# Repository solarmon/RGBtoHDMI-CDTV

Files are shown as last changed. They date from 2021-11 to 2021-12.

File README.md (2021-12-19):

# RGBtoHDMI-CDTV

## Introduction

This is an RGBtoHDMI solution is based on the original work by **hoglet67** and **IanSB**:

hoglet67:
https://github.com/hoglet67/RGBtoHDMI

IanSB:
https://github.com/IanSB/RGBtoHDMI

The solution is based on the RGBtoHDMI CPLD based hardware design by **LinuxJedi**:

https://github.com/LinuxJedi/AmigaRGBtoHDMI

Special mention to **c0pperdragon** for the original RGBtoHDMI board solution for the Amiga:

https://github.com/c0pperdragon/Amiga-Digital-Video

## Wiki

Please see the [wiki](https://github.com/solarmon/RGBtoHDMI-CDTV/wiki) for further details:

* [RGBtoHDMI CDTV Quick Start Guide](https://github.com/solarmon/RGBtoHDMI-CDTV/wiki/RGBtoHDMI-CDTV-Quick-Start-Guide)
* [RGBtoHDMI CDTV BoM](https://github.com/solarmon/RGBtoHDMI-CDTV/wiki/RGBtoHDMI-CDTV-BoM)
* [RGBtoHDMI CDTV Build Guide](https://github.com/solarmon/RGBtoHDMI-CDTV/wiki/RGBtoHDMI-CDTV-Build-Guide)

## Support

Please raise a [support ticket](https://github.com/solarmon/RGBtoHDMI-CDTV/issues) for any issues with this project content and design files.

## Solution

This RGBtoHDMI solution has been designed to fit in to the **Video Slot** of a **Commodore CDTV**. It replaces the existing RF and composite video card, as well as providing a **bypass** for the video signals to go to the **RGB** video port.

A breakout board is used to send the digital RGB signals from the Denise video chip, over a 18-pin FFC flex cable, to the main RGBtoHDMI board sitting in the Video Slot.

The mini HDMI connector of the **Raspberry Pi Zero** is presented directly on the face plate, along with three push buttons to control the RGBtoHDMI **OSD** menu.

This LinuxJedi CPLD based version supports either **OCS** or **ECS** Denise. There is no jumper required - you just need to make sure you **auto-calibrate** it using the OSD menu.

As with all the other RGBtoHDMI solution, **audio over HDMI** is currently **NOT supported**. This board does have breakout points for the **AUDL** and **AUDR** but is not used.

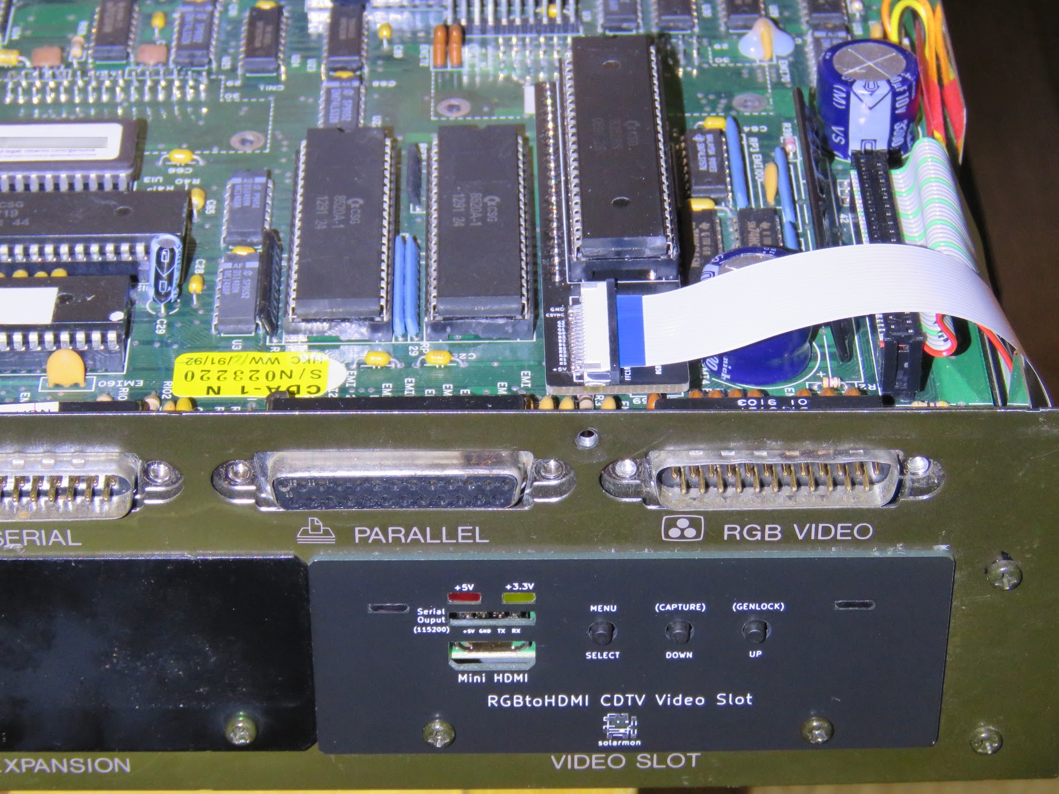
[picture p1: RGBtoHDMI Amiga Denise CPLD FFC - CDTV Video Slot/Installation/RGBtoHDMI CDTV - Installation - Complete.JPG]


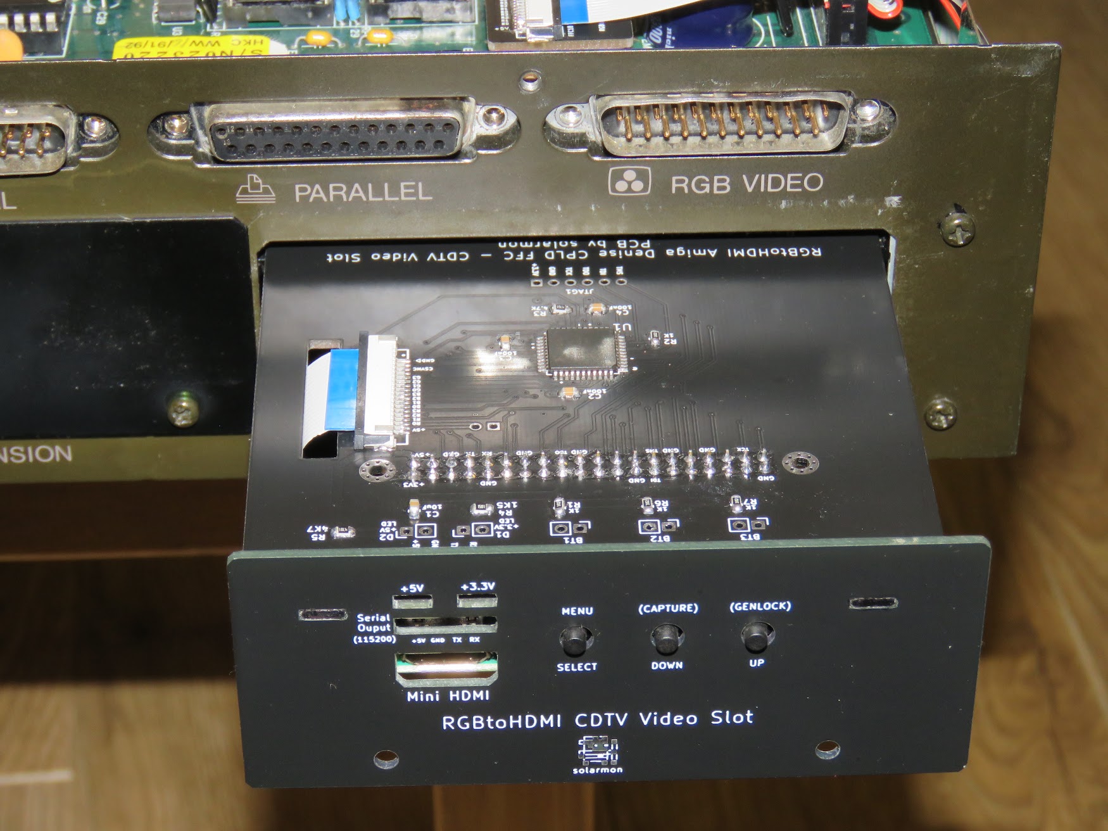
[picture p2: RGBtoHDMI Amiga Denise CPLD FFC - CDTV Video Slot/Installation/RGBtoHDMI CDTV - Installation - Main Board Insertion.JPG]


(...yes, I know the serial port and LEDs are missing in this picture! Oops!)

## Design

### RGBtoHDMI CDTV Main Board

Design files: https://github.com/solarmon/RGBtoHDMI-CDTV/tree/main/RGBtoHDMI%20Amiga%20Denise%20CPLD%20FFC%20-%20CDTV%20Video%20Slot

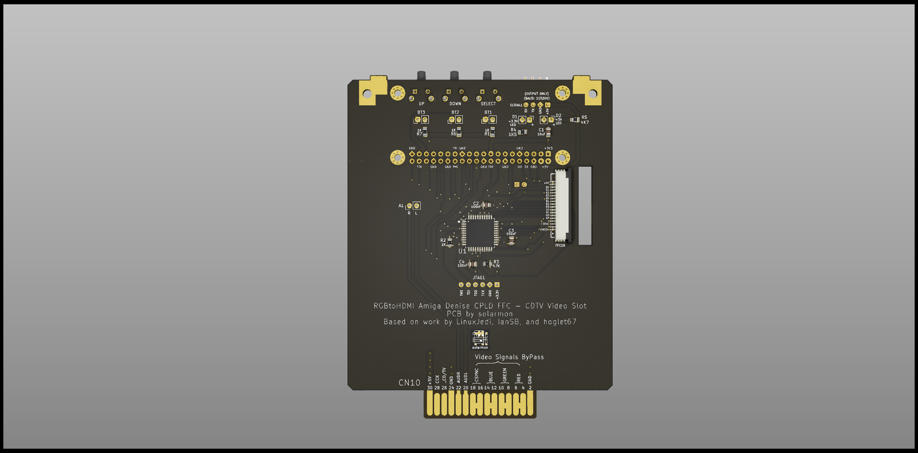
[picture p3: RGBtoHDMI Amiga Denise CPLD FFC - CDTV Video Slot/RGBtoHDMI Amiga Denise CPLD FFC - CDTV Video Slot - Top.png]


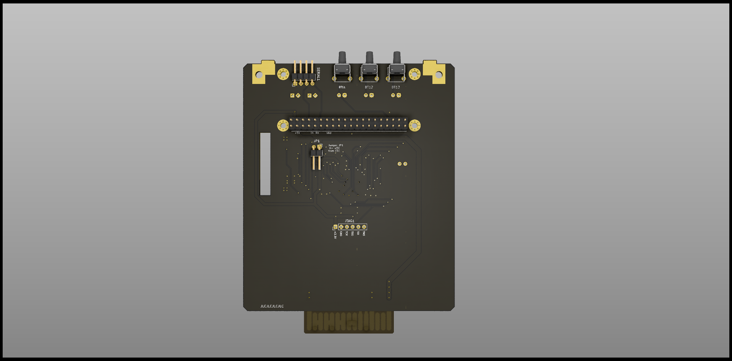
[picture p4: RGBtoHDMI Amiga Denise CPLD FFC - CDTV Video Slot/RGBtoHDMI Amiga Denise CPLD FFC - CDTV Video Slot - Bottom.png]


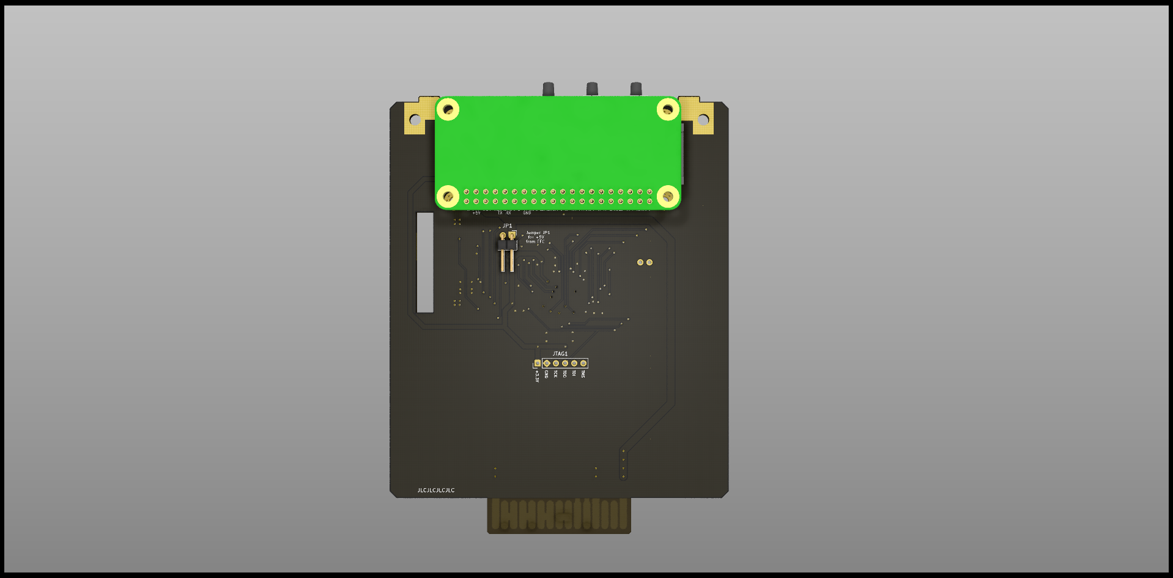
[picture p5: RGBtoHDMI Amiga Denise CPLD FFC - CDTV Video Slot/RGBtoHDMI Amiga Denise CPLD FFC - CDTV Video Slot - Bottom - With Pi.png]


### RGBtoHDMI CDTV Face Plate

Design files: https://github.com/solarmon/RGBtoHDMI-CDTV/tree/main/RGBtoHDMI%20Amiga%20Denise%20CPLD%20FFC%20-%20CDTV%20Video%20Slot

The face plate for the RGBtoHDMI CDTV board is also a PCB. It is attached to the main board using guide slots that has solder pads so that it can be soldered together.

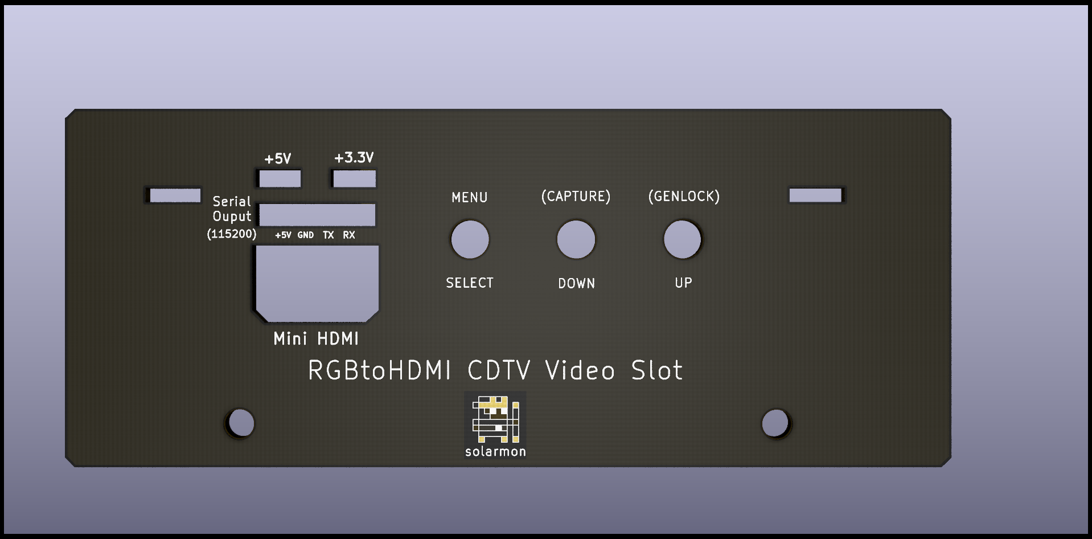
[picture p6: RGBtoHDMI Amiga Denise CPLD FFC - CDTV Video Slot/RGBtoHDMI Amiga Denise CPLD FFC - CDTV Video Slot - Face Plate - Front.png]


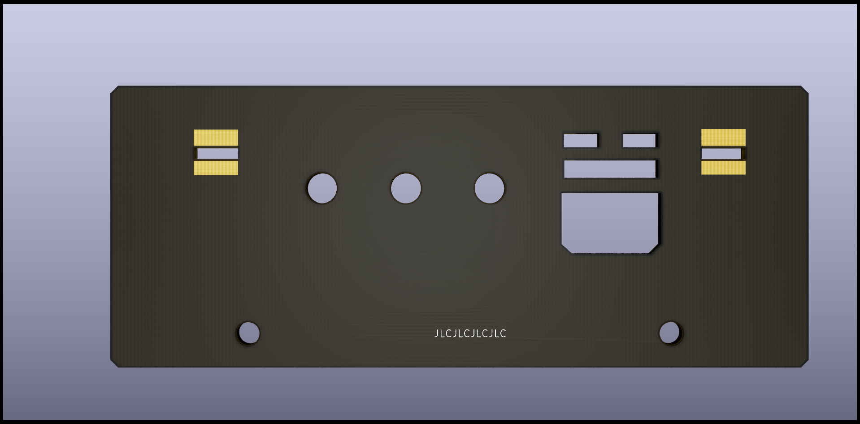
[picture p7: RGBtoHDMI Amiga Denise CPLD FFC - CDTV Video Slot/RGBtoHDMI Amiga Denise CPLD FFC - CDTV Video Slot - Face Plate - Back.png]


### RGBtoHDMI CDTV Denise Breakout board v1

Design files: https://github.com/solarmon/RGBtoHDMI-CDTV/tree/main/RGBtoHDMI%20Amiga%20Denise%20DIP%20Breakout%20FFC%20-%20CDTV

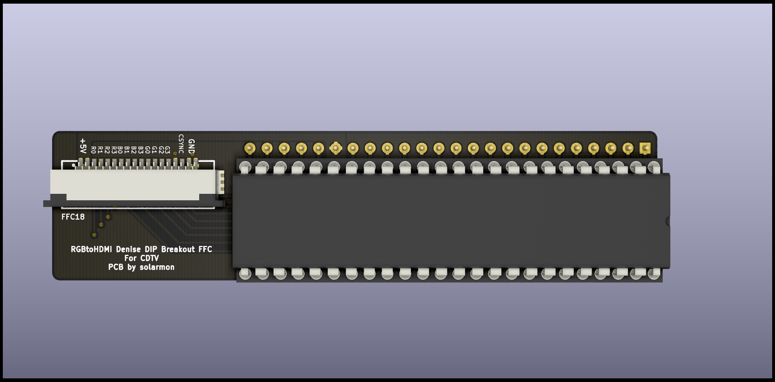
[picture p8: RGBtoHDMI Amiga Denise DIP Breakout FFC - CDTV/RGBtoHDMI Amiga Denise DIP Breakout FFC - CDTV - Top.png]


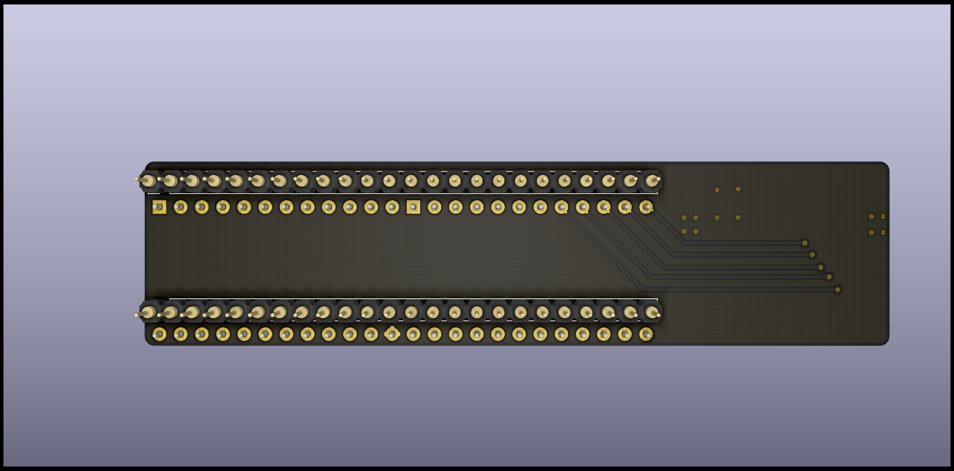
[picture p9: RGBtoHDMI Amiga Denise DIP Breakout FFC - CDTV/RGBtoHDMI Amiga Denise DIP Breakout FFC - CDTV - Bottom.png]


### RGBtoHDMI CDTV Denise Breakout board v2

Design files: https://github.com/solarmon/RGBtoHDMI-CDTV/tree/main/RGBtoHDMI%20Amiga%20Denise%20DIP%20Breakout%20FFC%20-%20CDTV%20v2

The v2 breakout board has a lower profile by using female round pins that act both as the socket for the Denise chip, as well as the pin to go in to the Denise socket on the CDTV.

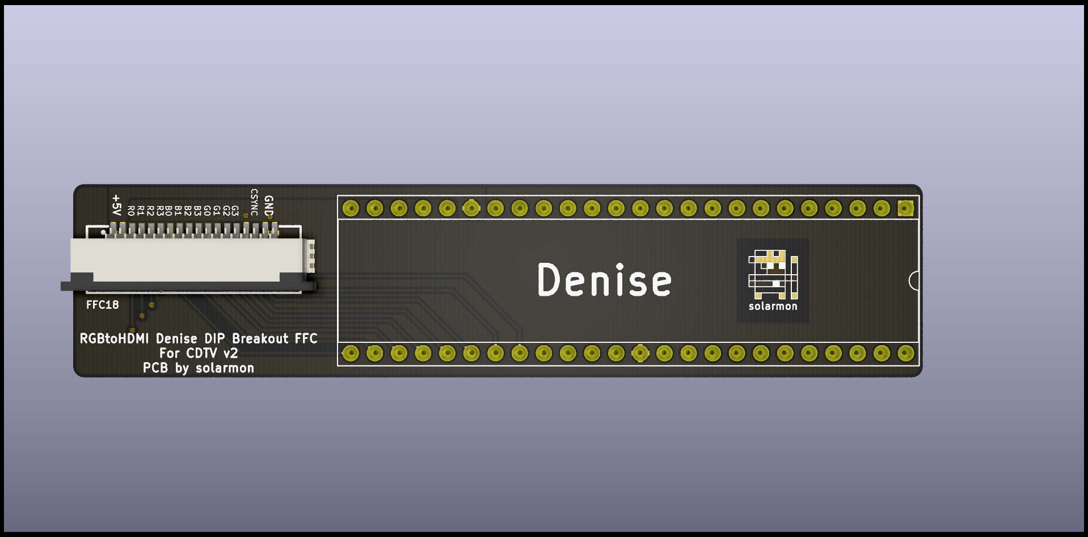
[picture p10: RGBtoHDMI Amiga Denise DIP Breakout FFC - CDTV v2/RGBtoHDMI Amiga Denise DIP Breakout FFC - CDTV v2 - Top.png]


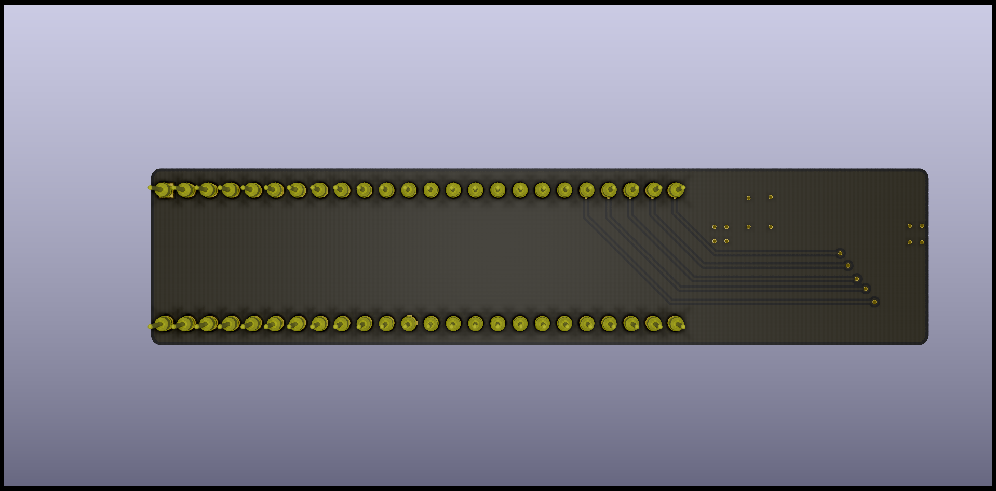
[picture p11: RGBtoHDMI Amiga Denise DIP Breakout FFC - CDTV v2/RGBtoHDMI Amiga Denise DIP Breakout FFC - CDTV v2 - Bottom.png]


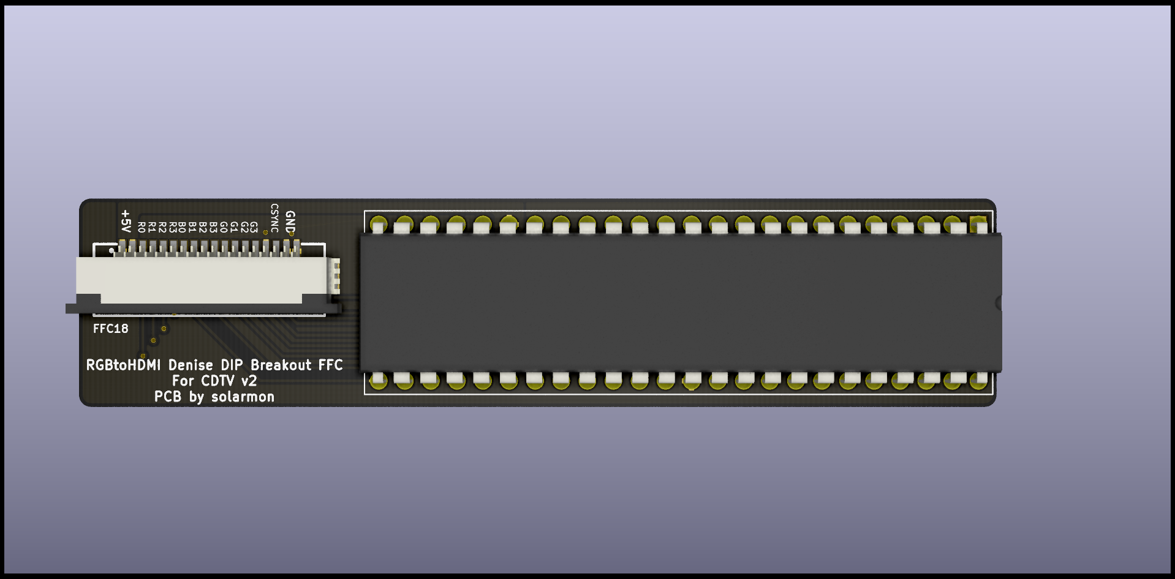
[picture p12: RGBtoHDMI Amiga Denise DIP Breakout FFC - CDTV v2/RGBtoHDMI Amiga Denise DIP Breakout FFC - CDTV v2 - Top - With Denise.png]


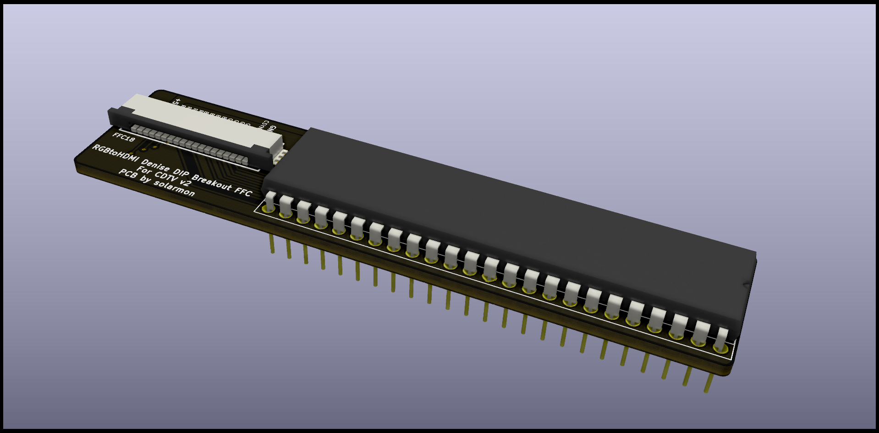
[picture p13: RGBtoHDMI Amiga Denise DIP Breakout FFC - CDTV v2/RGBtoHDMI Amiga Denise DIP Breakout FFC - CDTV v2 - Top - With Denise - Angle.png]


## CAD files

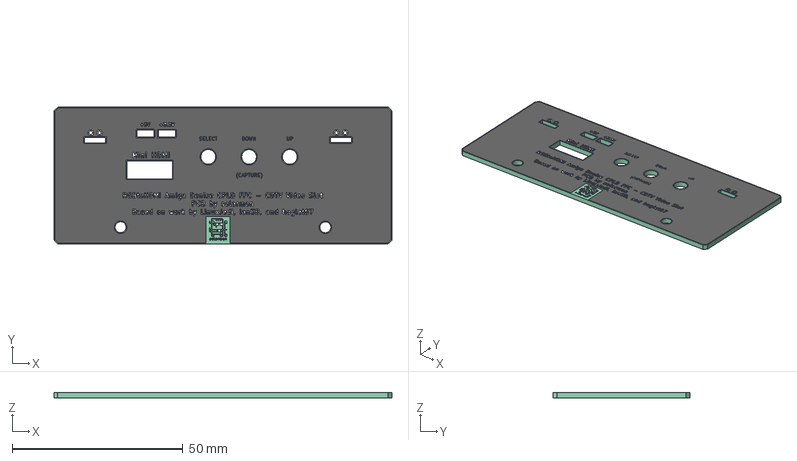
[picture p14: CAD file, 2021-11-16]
RGBtoHDMI Amiga Denise CPLD FFC - CDTV Video Slot/CDTV Front plate.FCStd
99.0 x 40.0 x 1.69 mm
Pcb_8674
topPads_8674
topZones_8674
botPads_8674
botZones_8674
topSilks_deb6

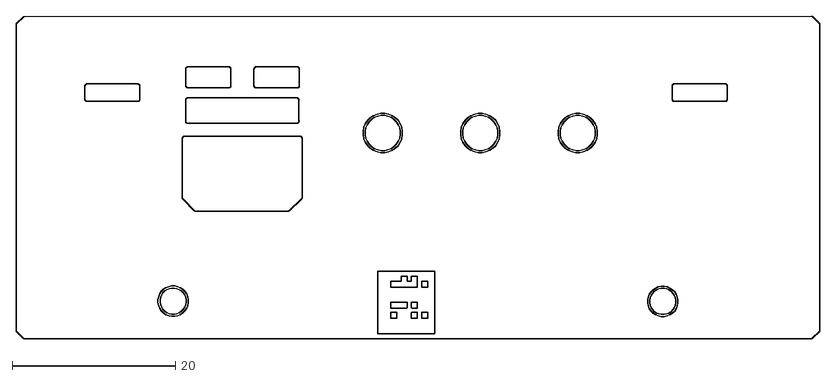
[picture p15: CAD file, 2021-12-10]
RGBtoHDMI Amiga Denise CPLD FFC - CDTV Video Slot/gerbers/face-plate/RGBtoHDMI Amiga Denise CPLD FFC - CDTV Video Slot - Face Plate-F_Cu.dxf
98.4 x 39.4

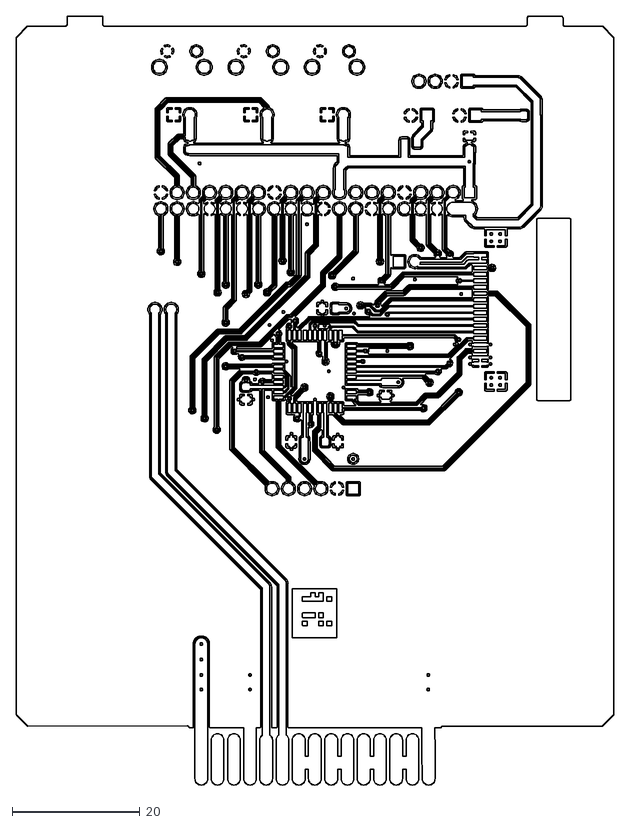
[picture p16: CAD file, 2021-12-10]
RGBtoHDMI Amiga Denise CPLD FFC - CDTV Video Slot/gerbers/video-slot/RGBtoHDMI Amiga Denise CPLD FFC - CDTV Video Slot-F_Cu.dxf
93.4 x 120.3

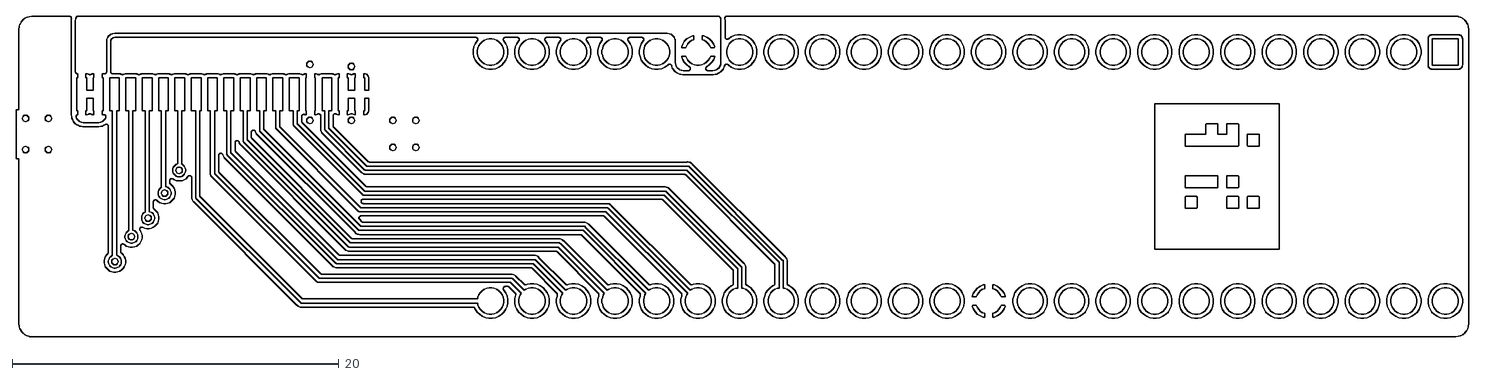
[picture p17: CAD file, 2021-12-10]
RGBtoHDMI Amiga Denise DIP Breakout FFC - CDTV v2/gerber/RGBtoHDMI Amiga Denise DIP Breakout FFC - CDTV v2-F_Cu.dxf
88.9 x 19.6

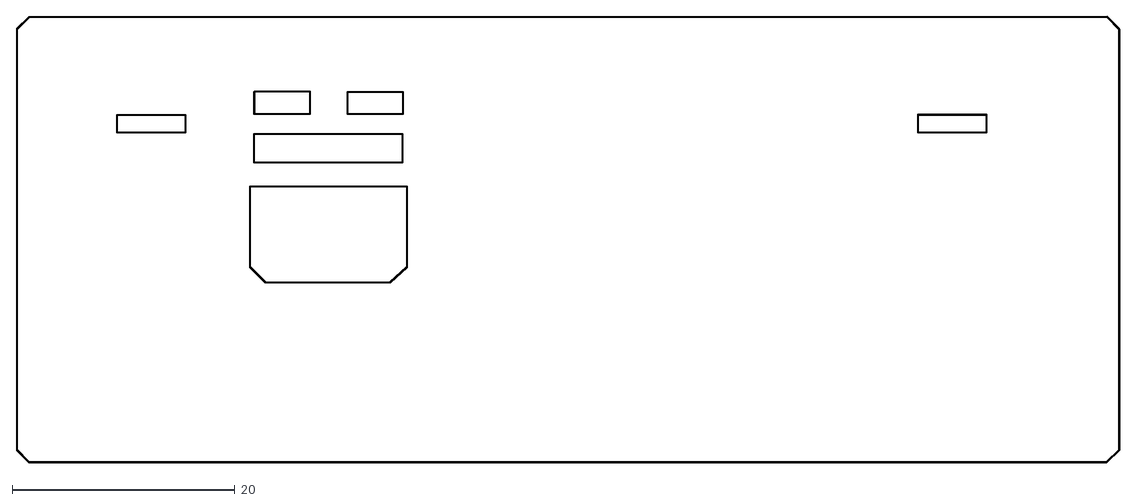
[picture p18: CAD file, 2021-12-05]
RGBtoHDMI Amiga Denise CPLD FFC - CDTV Video Slot/gerbers/face-plate/RGBtoHDMI Amiga Denise CPLD FFC - CDTV Video Slot - Face Plate-Edge_Cuts.dxf
99.0 x 40.1

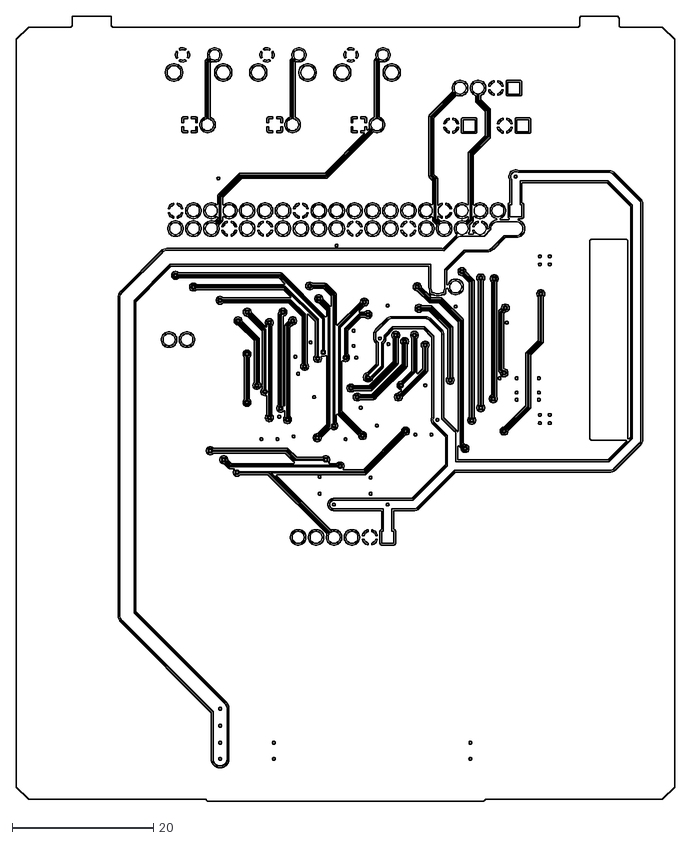
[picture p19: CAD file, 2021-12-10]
RGBtoHDMI Amiga Denise CPLD FFC - CDTV Video Slot/gerbers/video-slot/RGBtoHDMI Amiga Denise CPLD FFC - CDTV Video Slot-B_Cu.dxf
93.4 x 111.3

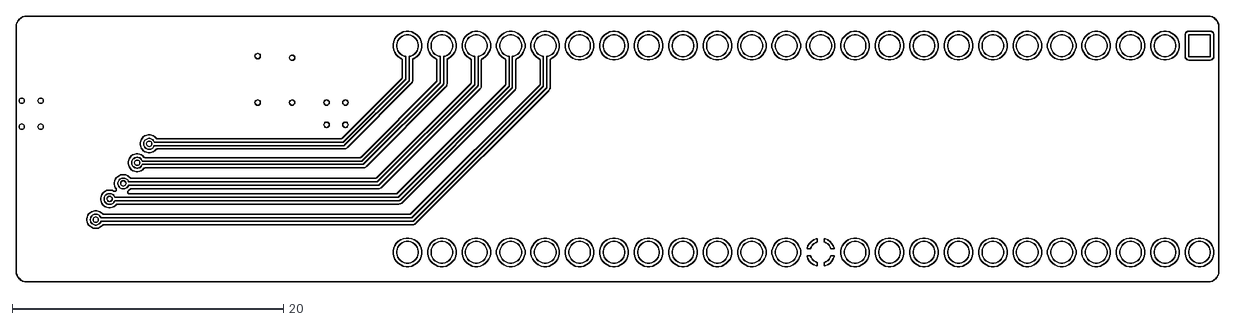
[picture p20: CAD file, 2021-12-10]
RGBtoHDMI Amiga Denise DIP Breakout FFC - CDTV v2/gerber/RGBtoHDMI Amiga Denise DIP Breakout FFC - CDTV v2-B_Cu.dxf
88.7 x 19.6

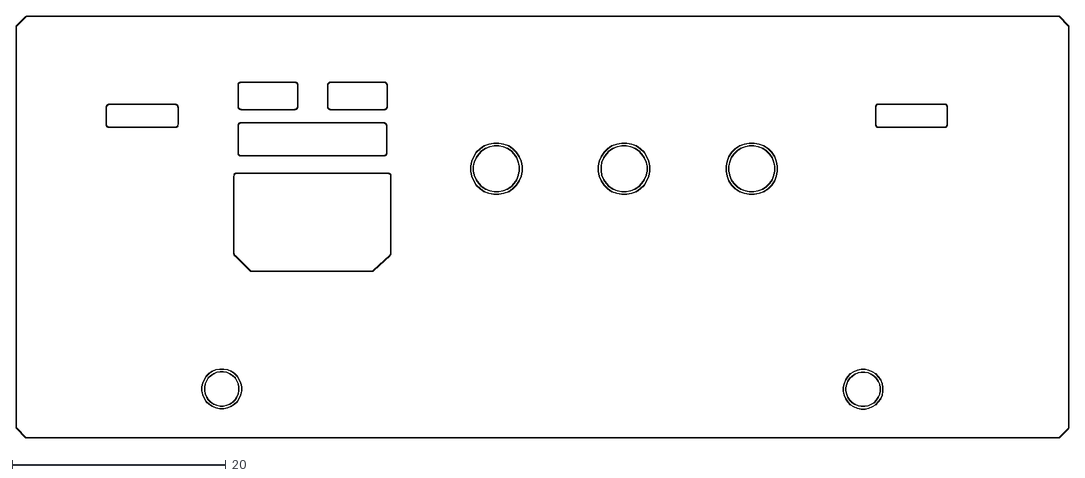
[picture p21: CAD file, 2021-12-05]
RGBtoHDMI Amiga Denise CPLD FFC - CDTV Video Slot/gerbers/face-plate/RGBtoHDMI Amiga Denise CPLD FFC - CDTV Video Slot - Face Plate-B_Cu.dxf
98.4 x 39.4

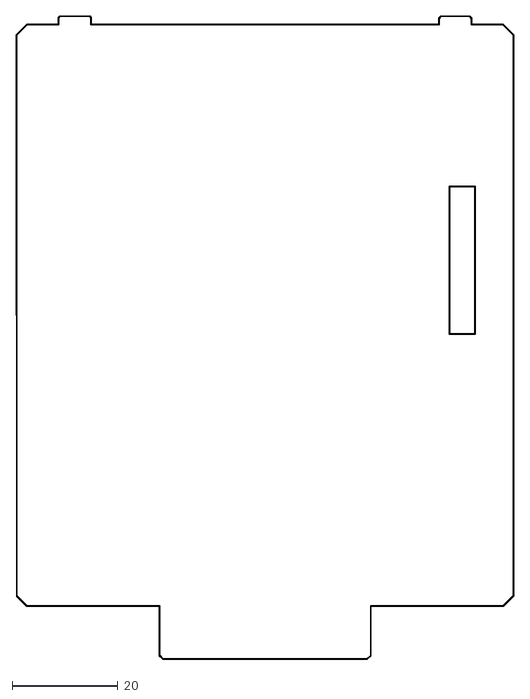
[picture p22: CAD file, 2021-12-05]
RGBtoHDMI Amiga Denise CPLD FFC - CDTV Video Slot/gerbers/video-slot/RGBtoHDMI Amiga Denise CPLD FFC - CDTV Video Slot-Edge_Cuts.dxf
94.0 x 121.6

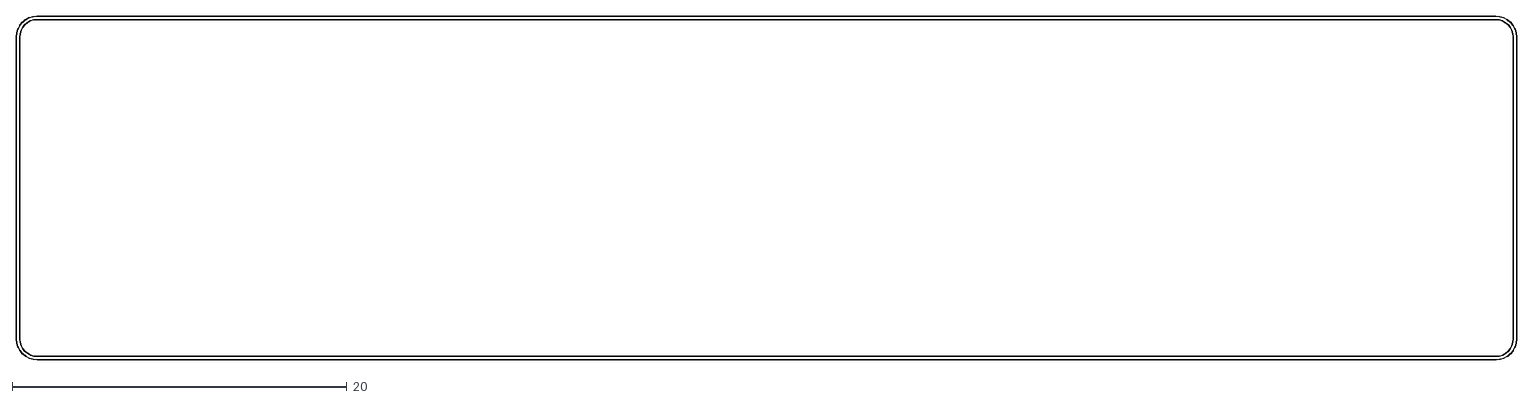
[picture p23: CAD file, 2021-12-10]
RGBtoHDMI Amiga Denise DIP Breakout FFC - CDTV v2/gerber/RGBtoHDMI Amiga Denise DIP Breakout FFC - CDTV v2-Edge_Cuts.dxf
89.6 x 20.5

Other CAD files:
RGBtoHDMI Amiga Denise CPLD FFC - CDTV Video Slot/gerbers/face-plate/RGBtoHDMI Amiga Denise CPLD FFC - CDTV Video Slot - Face Plate-B_Mask.dxf
RGBtoHDMI Amiga Denise CPLD FFC - CDTV Video Slot/gerbers/face-plate/RGBtoHDMI Amiga Denise CPLD FFC - CDTV Video Slot - Face Plate-B_SilkS.dxf
RGBtoHDMI Amiga Denise CPLD FFC - CDTV Video Slot/gerbers/face-plate/RGBtoHDMI Amiga Denise CPLD FFC - CDTV Video Slot - Face Plate-F_Mask.dxf
RGBtoHDMI Amiga Denise CPLD FFC - CDTV Video Slot/gerbers/face-plate/RGBtoHDMI Amiga Denise CPLD FFC - CDTV Video Slot - Face Plate-F_SilkS.dxf
RGBtoHDMI Amiga Denise CPLD FFC - CDTV Video Slot/gerbers/video-slot/RGBtoHDMI Amiga Denise CPLD FFC - CDTV Video Slot-B_Mask.dxf
RGBtoHDMI Amiga Denise CPLD FFC - CDTV Video Slot/gerbers/video-slot/RGBtoHDMI Amiga Denise CPLD FFC - CDTV Video Slot-B_SilkS.dxf
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

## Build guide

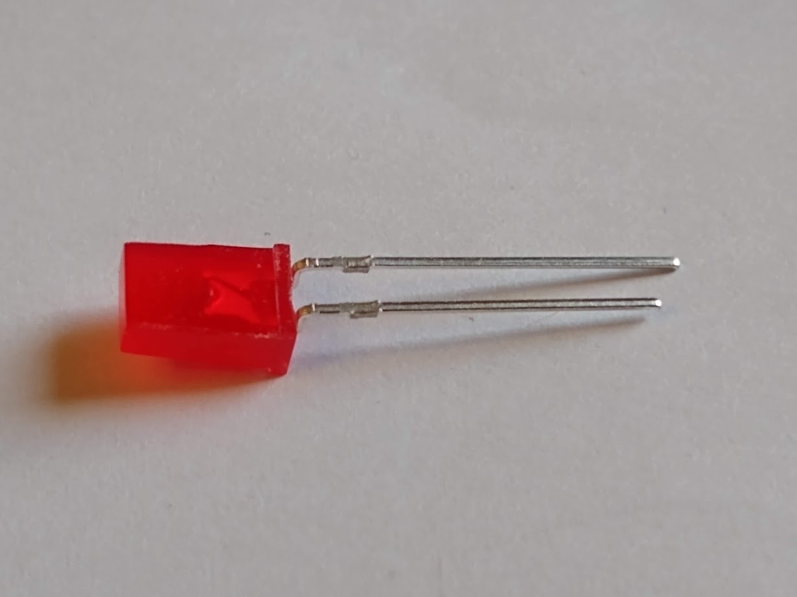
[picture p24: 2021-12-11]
RGBtoHDMI Amiga Denise CPLD FFC - CDTV Video Slot/Installation/RGBtoHDMI CDTV - LED - Legs Bent Back.jpg

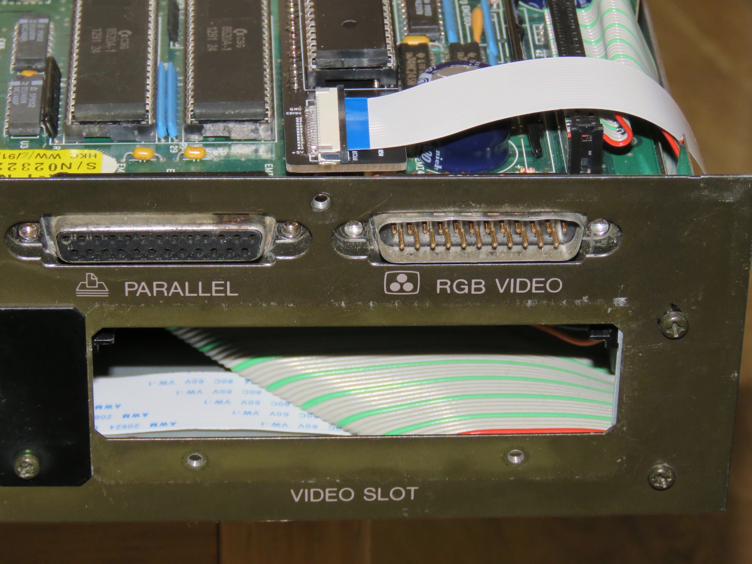
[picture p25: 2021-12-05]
RGBtoHDMI Amiga Denise CPLD FFC - CDTV Video Slot/Installation/RGBtoHDMI CDTV - Installation - Denise Break and Flex Cable - Rear.JPG

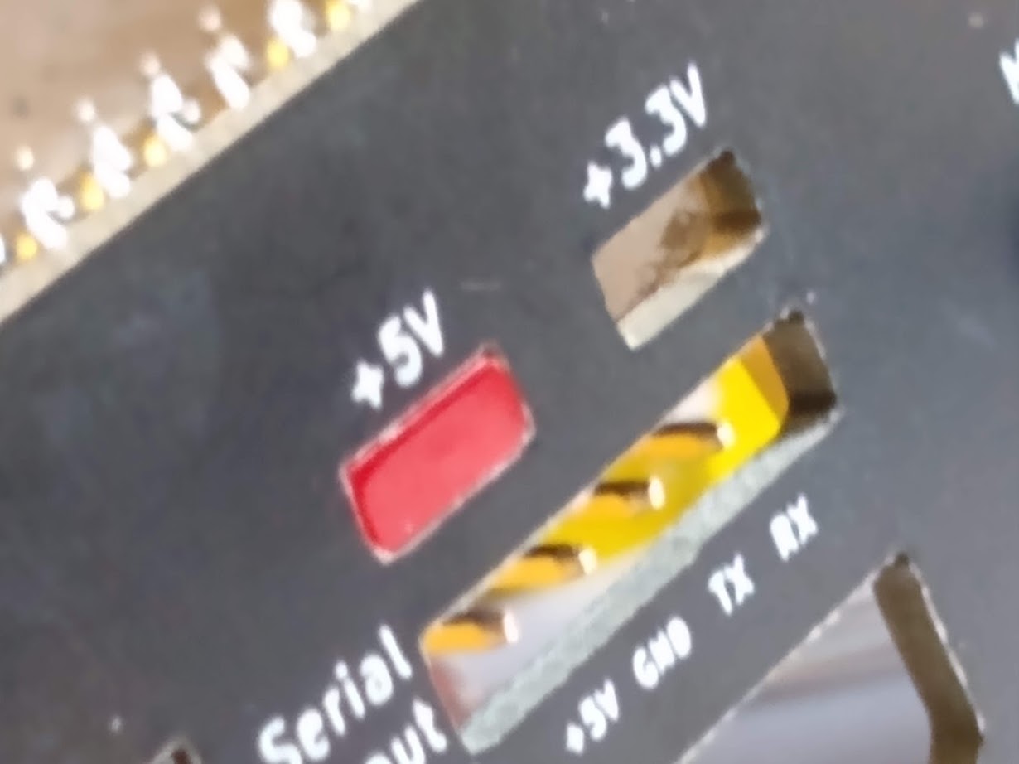
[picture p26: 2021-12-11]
RGBtoHDMI Amiga Denise CPLD FFC - CDTV Video Slot/Installation/RGBtoHDMI CDTV - LED - Flushed.jpg

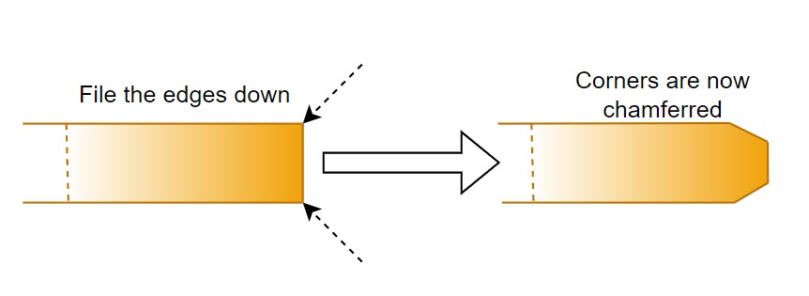
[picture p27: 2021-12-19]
RGBtoHDMI Amiga Denise CPLD FFC - CDTV Video Slot/Installation/RGBtoHDMI CDTV - Mount Slots - Chamfered CN10 Edge.jpg

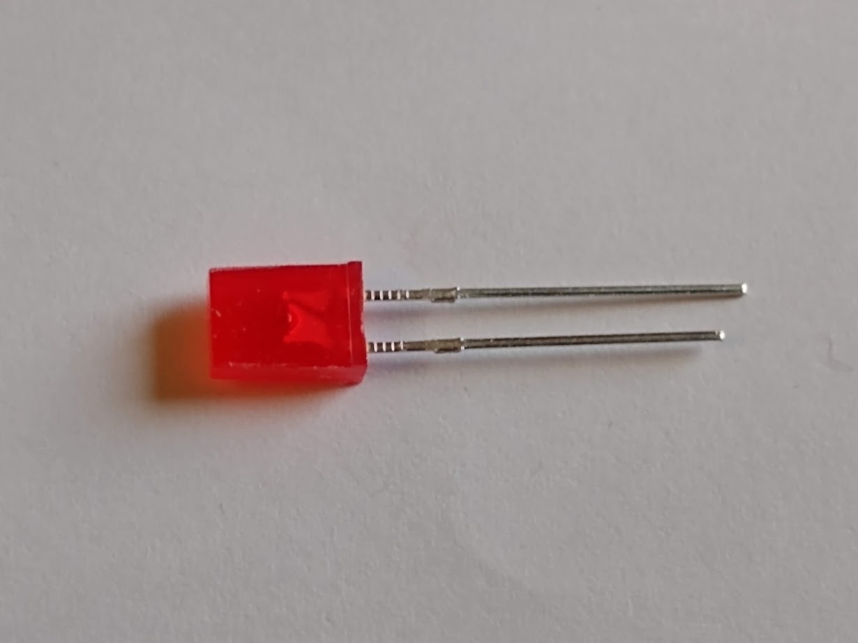
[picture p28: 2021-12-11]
RGBtoHDMI Amiga Denise CPLD FFC - CDTV Video Slot/Installation/RGBtoHDMI CDTV - LED.jpg

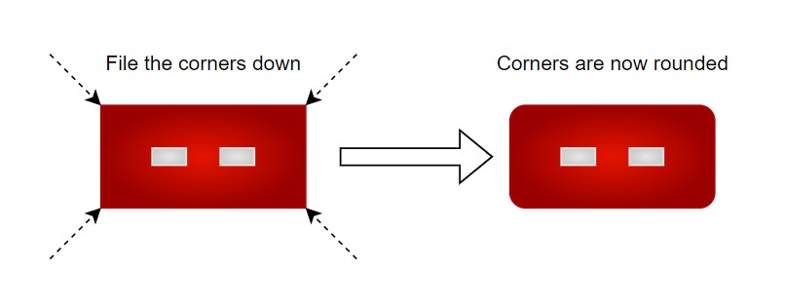
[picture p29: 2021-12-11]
RGBtoHDMI Amiga Denise CPLD FFC - CDTV Video Slot/Installation/RGBtoHDMI CDTV - LED - Rounded Corners.jpg

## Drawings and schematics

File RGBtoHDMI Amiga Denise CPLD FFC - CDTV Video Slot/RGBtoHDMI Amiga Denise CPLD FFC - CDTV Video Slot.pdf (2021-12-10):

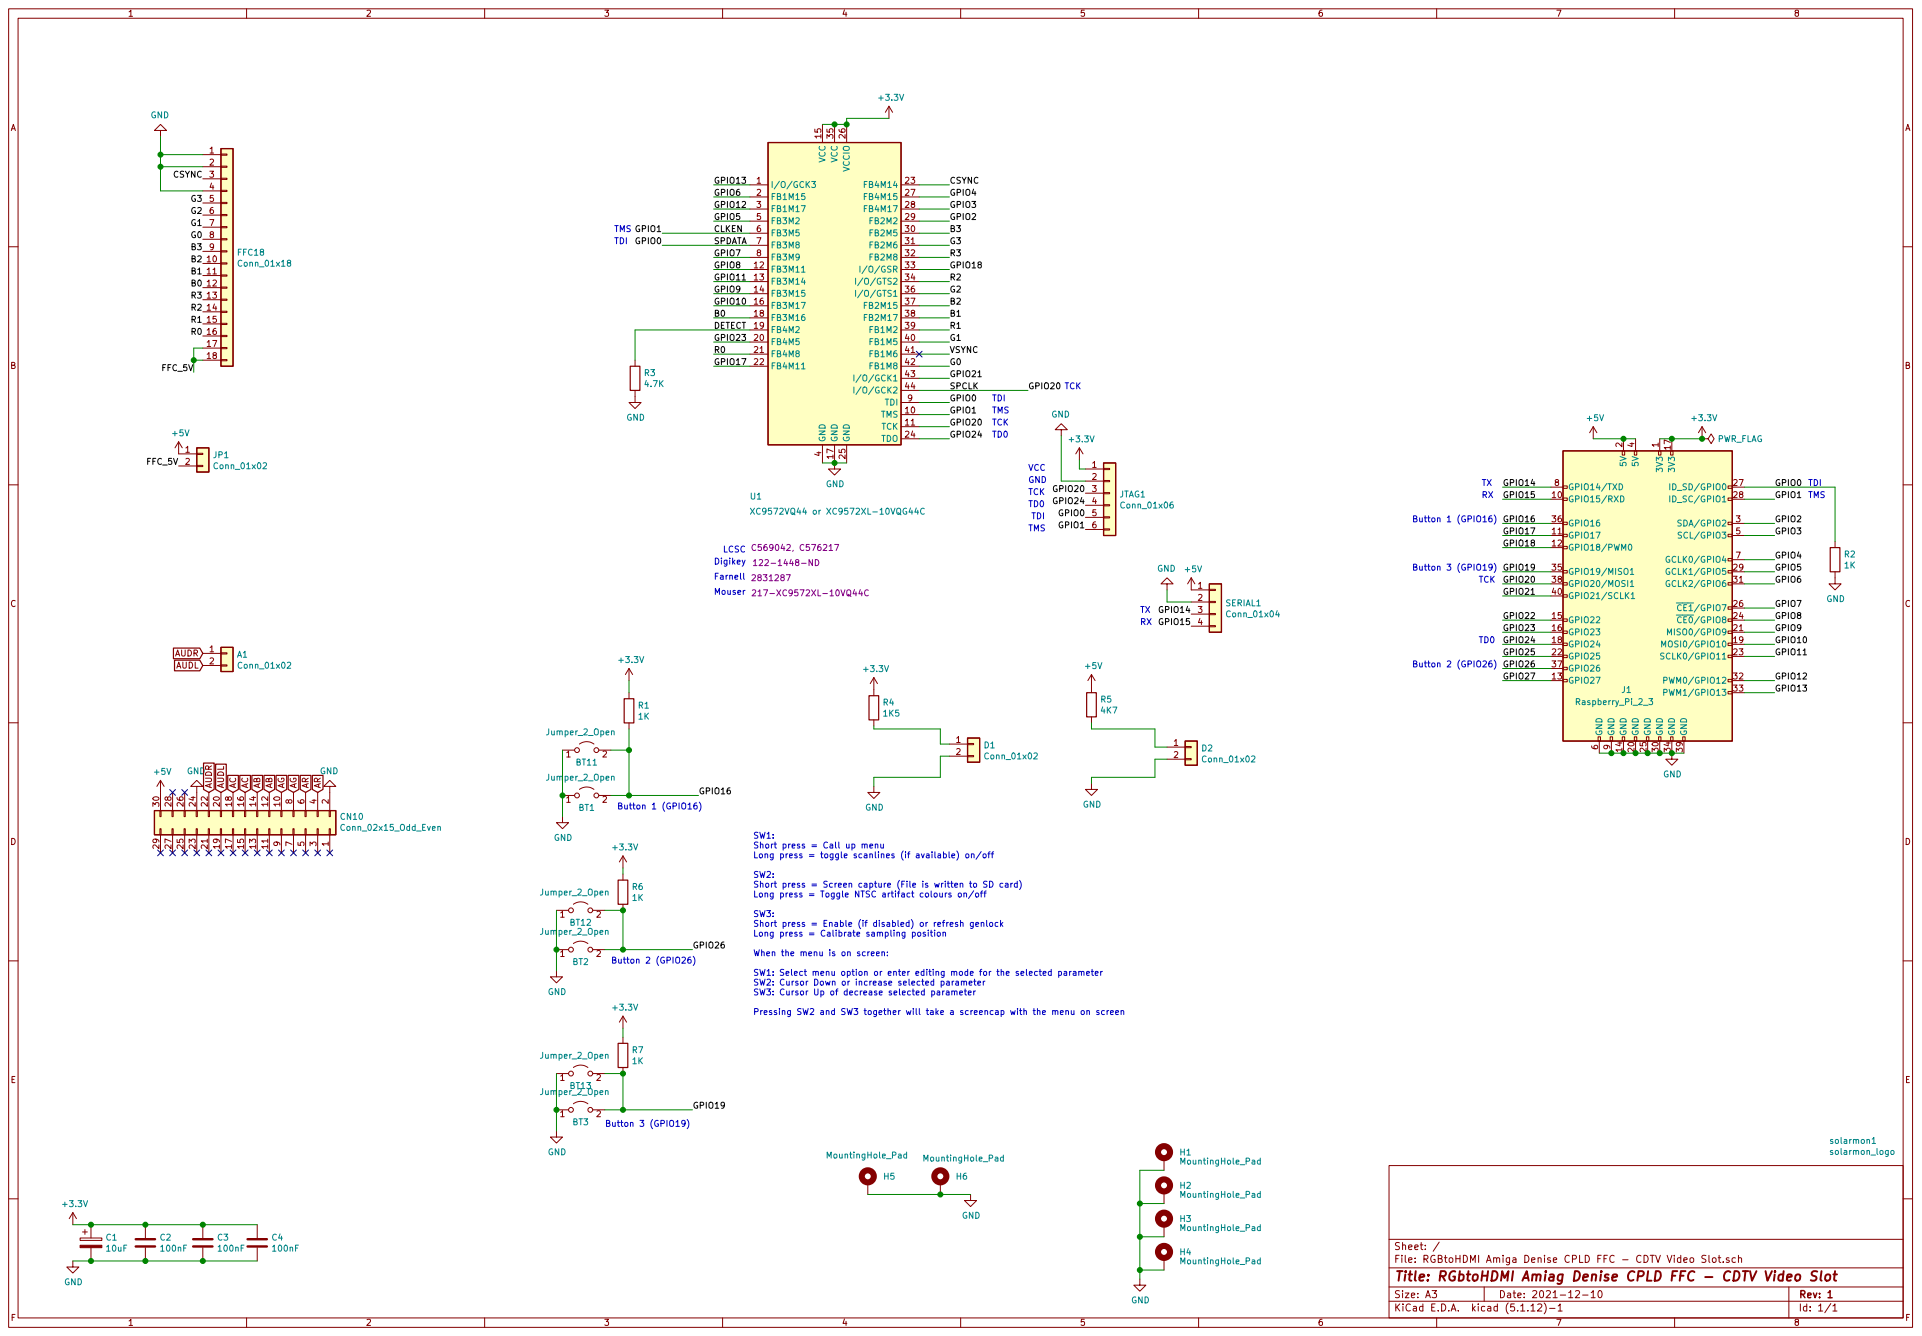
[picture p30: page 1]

File: RGBtoHDMI Amiga Denise CPLD FFC - CDTV Video Slot.sch Sheet: / GND
+3.3V GND

Long press = toggle scanlines (if available) on/off SW2: Short press = Screen capture (File is written to SD card)

Long press = Toggle NTSC artifact colours on/off SW3: Short press = Enable (if disabled) or refresh genlock

Long press = Calibrate sampling position When the menu is on screen: SW1: Select menu option or enter editing mode for the selected parameter

SW2: Cursor Down or increase selected parameter
SW3: Cursor Up of decrease selected parameter

Pressing SW2 and SW3 together will take a screencap with the menu on screen

Id: 1/1 Title: RGbtoHDMI Amiag Denise CPLD FFC - CDTV Video Slot

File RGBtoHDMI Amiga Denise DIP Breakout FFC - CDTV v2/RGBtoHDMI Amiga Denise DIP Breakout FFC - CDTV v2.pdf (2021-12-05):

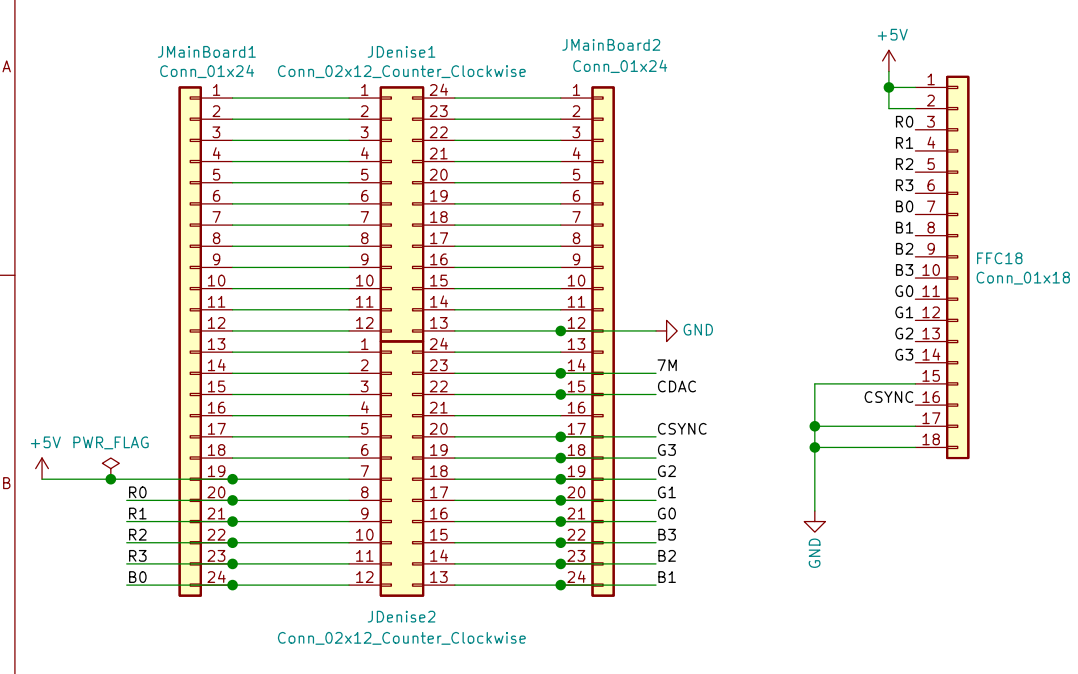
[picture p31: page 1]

2 2 | 23 2
3 3 | 22 3
4 4 | 21 4
5 5 | 20 5
6 6 | 19 6
7 7 | 18 7
8 8 | 17 8
9 9 | 16 9
10 10 | 15 10
11 11 | 14 11
12 12 | 13 12 24 13

File: RGBtoHDMI Amiga Denise DIP Breakout FFC - CDTV.sch Sheet: /
Id: 1/1 Title: RGBtoHDMI Amiga Denise DIP Breakout - CDTV

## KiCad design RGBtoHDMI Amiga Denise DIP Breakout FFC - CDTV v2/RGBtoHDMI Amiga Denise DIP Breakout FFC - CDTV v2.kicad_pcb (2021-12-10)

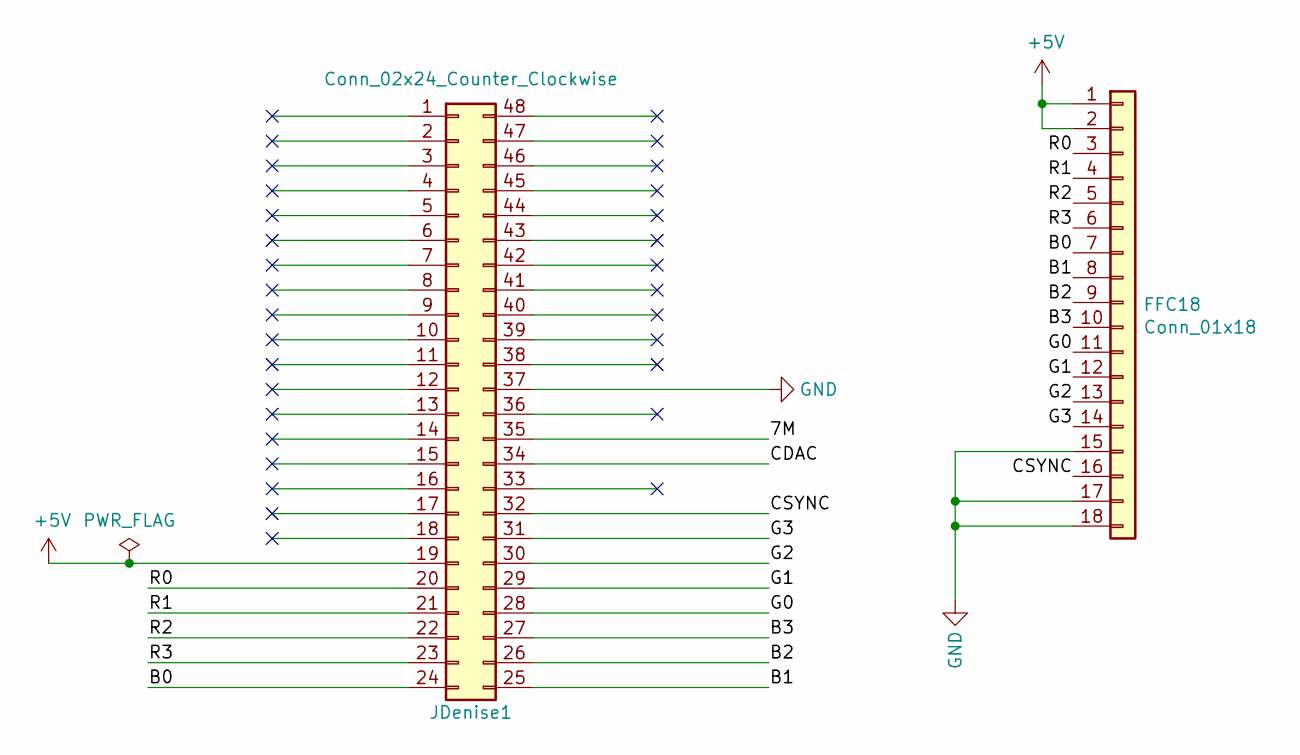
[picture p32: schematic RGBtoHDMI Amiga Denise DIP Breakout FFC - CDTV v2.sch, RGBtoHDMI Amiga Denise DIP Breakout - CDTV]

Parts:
FFC18: Conn_01x18; FPC-SMD_X10B25U18T
JDenise1: Conn_02x24_Counter_Clockwise; DIP-48_W15.24mm_Socket_Turned_Pins

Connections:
+5V: FFC18.1, FFC18.2, JDenise1.19
/7M: JDenise1.35
/B0: FFC18.7, JDenise1.24
/B1: FFC18.8, JDenise1.25
/B2: FFC18.9, JDenise1.26
/B3: FFC18.10, JDenise1.27
/CDAC: JDenise1.34
/CSYNC: FFC18.16, JDenise1.32
/G0: FFC18.11, JDenise1.28
/G1: FFC18.12, JDenise1.29
/G2: FFC18.13, JDenise1.30
/G3: FFC18.14, JDenise1.31
/R0: FFC18.3, JDenise1.20
/R1: FFC18.4, JDenise1.21
/R2: FFC18.5, JDenise1.22
/R3: FFC18.6, JDenise1.23
GND: FFC18.15, FFC18.17, FFC18.18, FFC18.MP, JDenise1.37

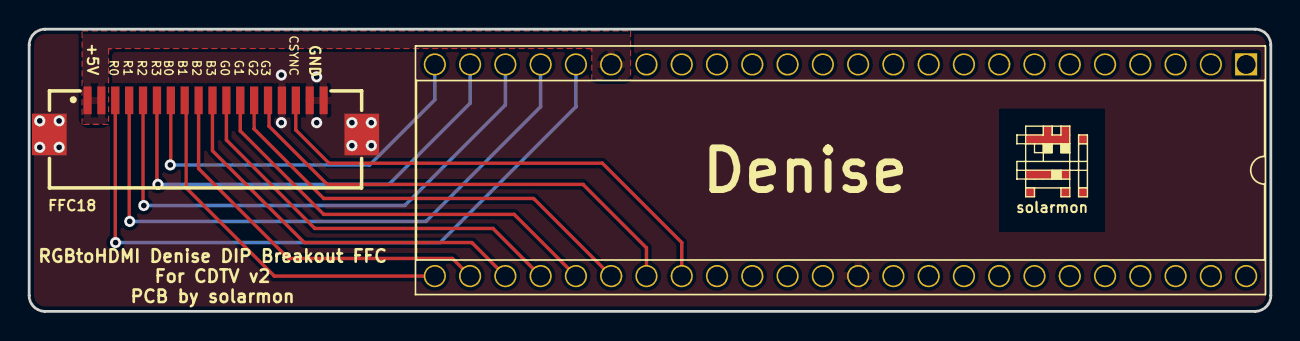
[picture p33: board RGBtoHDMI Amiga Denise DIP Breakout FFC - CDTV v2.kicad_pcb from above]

Board: 2 copper layers, 89.4 x 20.3 mm, 3 parts (0 on the bottom side), 15 nets.

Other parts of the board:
solarmon: solarmon-logo-25mils

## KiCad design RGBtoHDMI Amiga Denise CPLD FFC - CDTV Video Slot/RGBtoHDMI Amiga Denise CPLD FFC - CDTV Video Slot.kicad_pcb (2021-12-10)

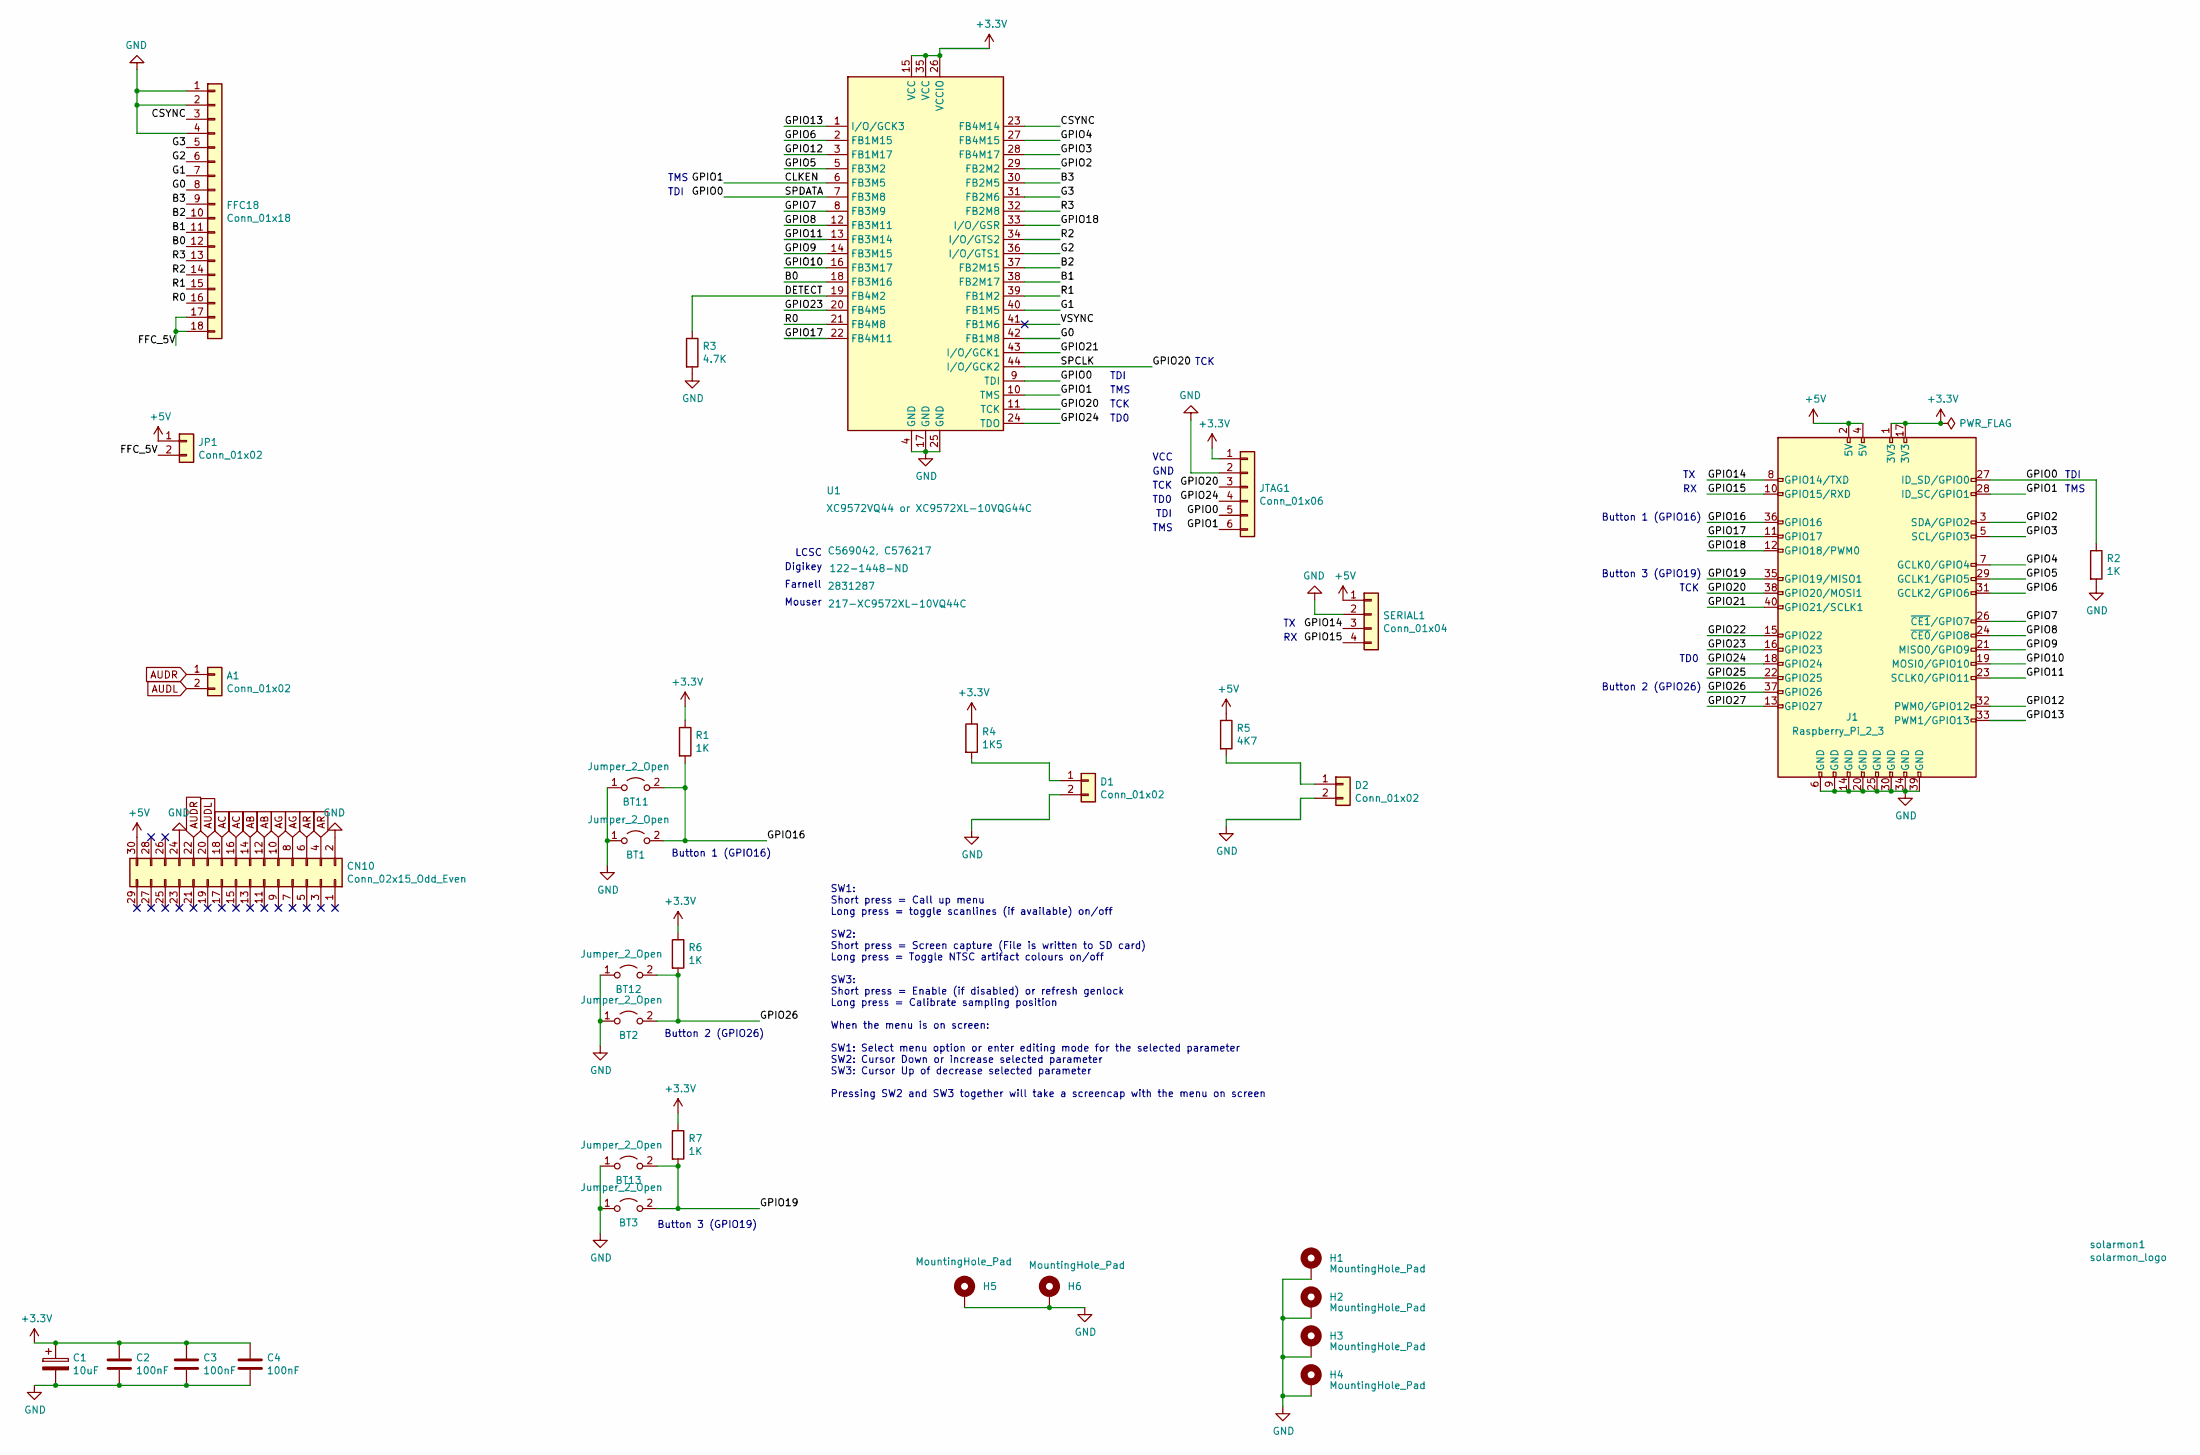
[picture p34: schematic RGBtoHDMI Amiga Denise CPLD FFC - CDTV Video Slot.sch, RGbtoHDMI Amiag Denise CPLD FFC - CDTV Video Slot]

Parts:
A1: Conn_01x02; PinHeader_1x02_P2.54mm_Vertical
BT1, BT2, BT3: Jumper_2_Open; PinHeader_1x02_P2.54mm_Vertical
BT11, BT12, BT13: Jumper_2_Open; PUSH_BUTTON_RIGHT_ANGLE
C1: 10uF; C_0805_2012Metric_Pad1.18x1.45mm_HandSolder
C2, C3, C4: 100nF; C_0805_2012Metric_Pad1.18x1.45mm_HandSolder
CN10: Conn_02x15_Odd_Even; CDTV_Video_Slot_30_pin
D1, D2: Conn_01x02; PinHeader_1x02_P2.54mm_Vertical
FFC18: Conn_01x18; FPC-SMD_X10B25U18T
H1, H2, H3, H4: MountingHole_Pad; MountingHole_2.5mm_Pad_Via
H5, H6: MountingHole_Pad; MountingHole_3.2mm_M3
J1: Raspberry_Pi_2_3; PinSocket_2x20_P2.54mm_Vertical
JP1: Conn_01x02; PinHeader_1x02_P2.54mm_Horizontal
JTAG1: Conn_01x06; PinHeader_1x06_P2.54mm_Vertical
R1, R2, R6, R7: 1K; R_0805_2012Metric_Pad1.20x1.40mm_HandSolder
R3: 4.7K; R_0805_2012Metric_Pad1.20x1.40mm_HandSolder
R4: 1K5; R_0805_2012Metric_Pad1.20x1.40mm_HandSolder
R5: 4K7; R_0805_2012Metric_Pad1.20x1.40mm_HandSolder
SERIAL1: Conn_01x04; PinHeader_1x04_P2.54mm_Horizontal
U1: XC9572VQ44 or XC9572XL-10VQG44C; TQFP-44_10x10mm_P0.8mm; LCSC C569042, C576217
solarmon1: solarmon_logo; solarmon-logo-25mils

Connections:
+3V3: C1.1, C2.1, C3.1, C4.1, J1.1 (3V3), J1.17 (3V3), JTAG1.1, R1.1, R4.1, R6.1, R7.1, U1.15 (VCC), U1.26 (VCCIO), U1.35 (VCC)
+5V: CN10.30, J1.2 (5V), J1.4 (5V), JP1.1, R5.1, SERIAL1.1
/B0: FFC18.12, U1.18 (FB3M16)
/B1: FFC18.11, U1.38 (FB2M17)
/B2: FFC18.10, U1.37 (FB2M15)
/B3: FFC18.9, U1.30 (FB2M5)
/CLKEN: J1.28 (ID_SC/GPIO1), JTAG1.6, U1.6 (FB3M5), U1.10 (TMS)
/CSYNC: FFC18.3, U1.23 (FB4M14)
/DETECT: R3.1, U1.19 (FB4M2)
/FFC_5V: FFC18.17, FFC18.18, JP1.2
/G0: FFC18.8, U1.42 (FB1M8)
/G1: FFC18.7, U1.40 (FB1M5)
/G2: FFC18.6, U1.36 (I/O/GTS1)
/G3: FFC18.5, U1.31 (FB2M6)
/GPIO0: J1.27 (ID_SD/GPIO0), JTAG1.5, R2.1, U1.7 (FB3M8), U1.9 (TDI)
/GPIO2: J1.3 (SDA/GPIO2), U1.29 (FB2M2)
/GPIO3: J1.5 (SCL/GPIO3), U1.28 (FB4M17)
/GPIO4: J1.7 (GCLK0/GPIO4), U1.27 (FB4M15)
/GPIO5: J1.29 (GCLK1/GPIO5), U1.5 (FB3M2)
/GPIO6: J1.31 (GCLK2/GPIO6), U1.2 (FB1M15)
/GPIO7: J1.26 (~CE1~/GPIO7), U1.8 (FB3M9)
/GPIO8: J1.24 (~CE0~/GPIO8), U1.12 (FB3M11)
/GPIO9: J1.21 (MISO0/GPIO9), U1.14 (FB3M15)
/GPIO10: J1.19 (MOSI0/GPIO10), U1.16 (FB3M17)
/GPIO11: J1.23 (SCLK0/GPIO11), U1.13 (FB3M14)
/GPIO12: J1.32 (PWM0/GPIO12), U1.3 (FB1M17)
/GPIO13: J1.33 (PWM1/GPIO13), U1.1 (I/O/GCK3)
/GPIO14: J1.8 (GPIO14/TXD), SERIAL1.3
/GPIO15: J1.10 (GPIO15/RXD), SERIAL1.4
/GPIO16: BT1.2 (B), BT11.2 (B), J1.36 (GPIO16), R1.2
/GPIO17: J1.11 (GPIO17), U1.22 (FB4M11)
/GPIO18: J1.12 (GPIO18/PWM0), U1.33 (I/O/GSR)
/GPIO19: BT3.2 (B), BT13.2 (B), J1.35 (GPIO19/MISO1), R7.2
/GPIO20: J1.38 (GPIO20/MOSI1), JTAG1.3, U1.11 (TCK), U1.44 (I/O/GCK2)
/GPIO21: J1.40 (GPIO21/SCLK1), U1.43 (I/O/GCK1)
/GPIO22: J1.15 (GPIO22)
/GPIO23: J1.16 (GPIO23), U1.20 (FB4M5)
/GPIO24: J1.18 (GPIO24), JTAG1.4, U1.24 (TDO)
/GPIO25: J1.22 (GPIO25)
/GPIO26: BT2.2 (B), BT12.2 (B), J1.37 (GPIO26), R6.2
/GPIO27: J1.13 (GPIO27)
/R0: FFC18.16, U1.21 (FB4M8)
/R1: FFC18.15, U1.39 (FB1M2)
/R2: FFC18.14, U1.34 (I/O/GTS2)
/R3: FFC18.13, U1.32 (FB2M8)
/VSYNC: U1.41 (FB1M6)
AB: CN10.12, CN10.14
AC: CN10.16, CN10.18
AG: CN10.8, CN10.10
AR: CN10.4, CN10.6
AUDL: A1.2, CN10.20
AUDR: A1.1, CN10.22
GND: BT1.1 (A), BT2.1 (A), BT3.1 (A), BT11.1 (A), BT12.1 (A), BT13.1 (A), C1.2, C2.2, C3.2, C4.2, CN10.2, CN10.24, D1.2, D2.2, FFC18.1, FFC18.2, FFC18.4, FFC18.MP, H1.1, H2.1, H3.1, H4.1, H5.1, H6.1, J1.6 (GND), J1.9 (GND), J1.14 (GND), J1.20 (GND), J1.25 (GND), J1.30 (GND), J1.34 (GND), J1.39 (GND), JTAG1.2, R2.2, R3.2, SERIAL1.2, U1.4 (GND), U1.17 (GND), U1.25 (GND)
unnamed: D1.1, R4.2
unnamed: D2.1, R5.2

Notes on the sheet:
TCK
TMS
TDI
TD0
GND
VCC
Button 1 (GPIO16)
Button 2 (GPIO26)
Button 3 (GPIO19)
Farnell
Digikey
LCSC
Mouser
SW1: Short press = Call up menu Long press = toggle scanlines (if available) on/off SW2: Short press = Screen capture (File is written to SD card) Long press = Toggle NTSC artifact colours on/off SW3: Short press = Enable (if disabled) or refresh genlock Long press = Calibrate sampling position Whe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

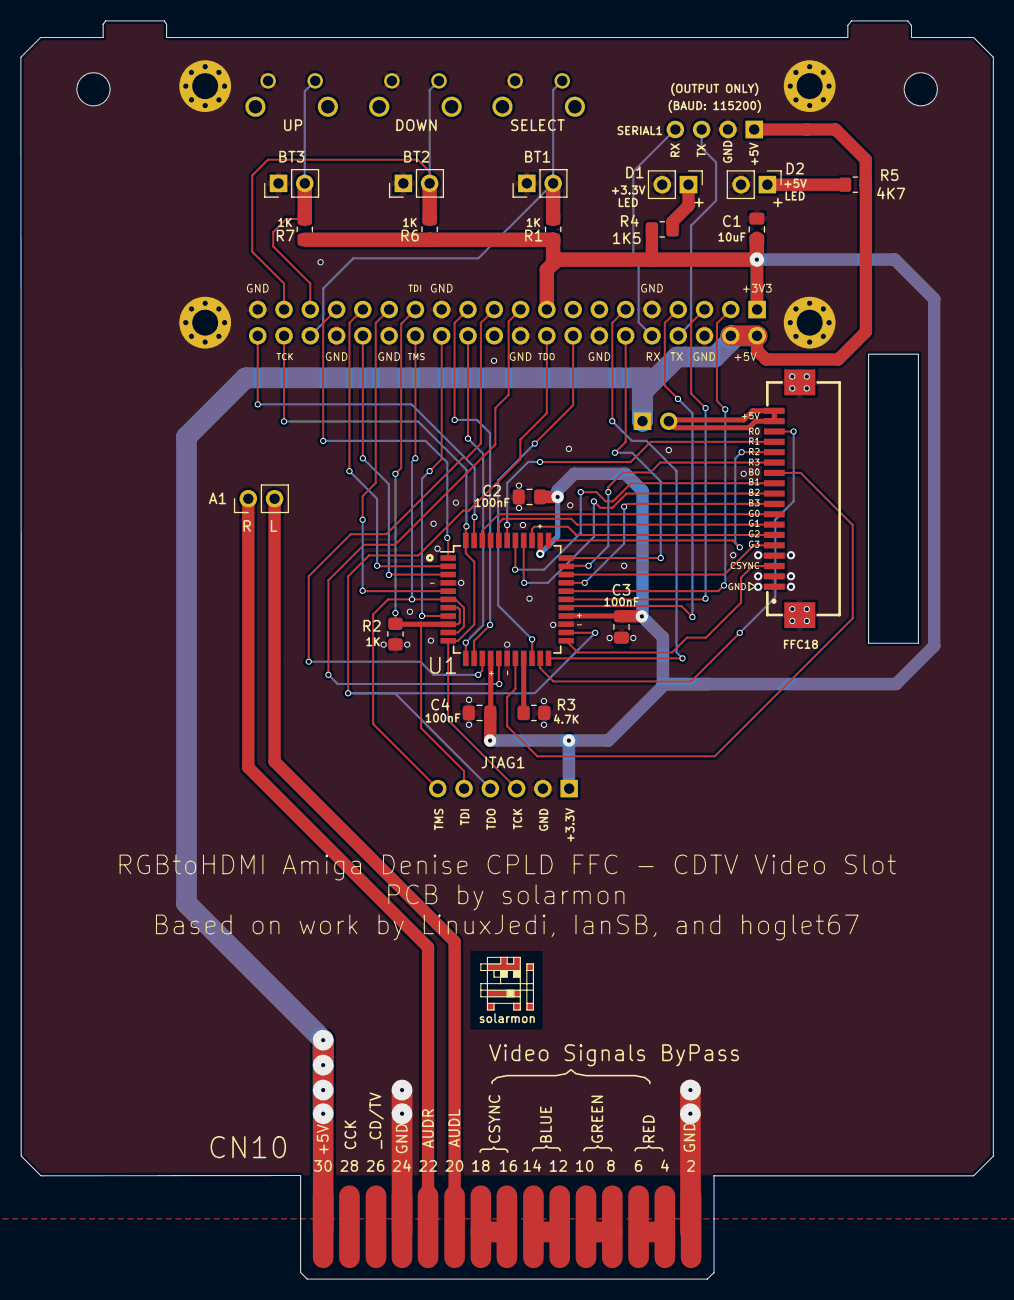
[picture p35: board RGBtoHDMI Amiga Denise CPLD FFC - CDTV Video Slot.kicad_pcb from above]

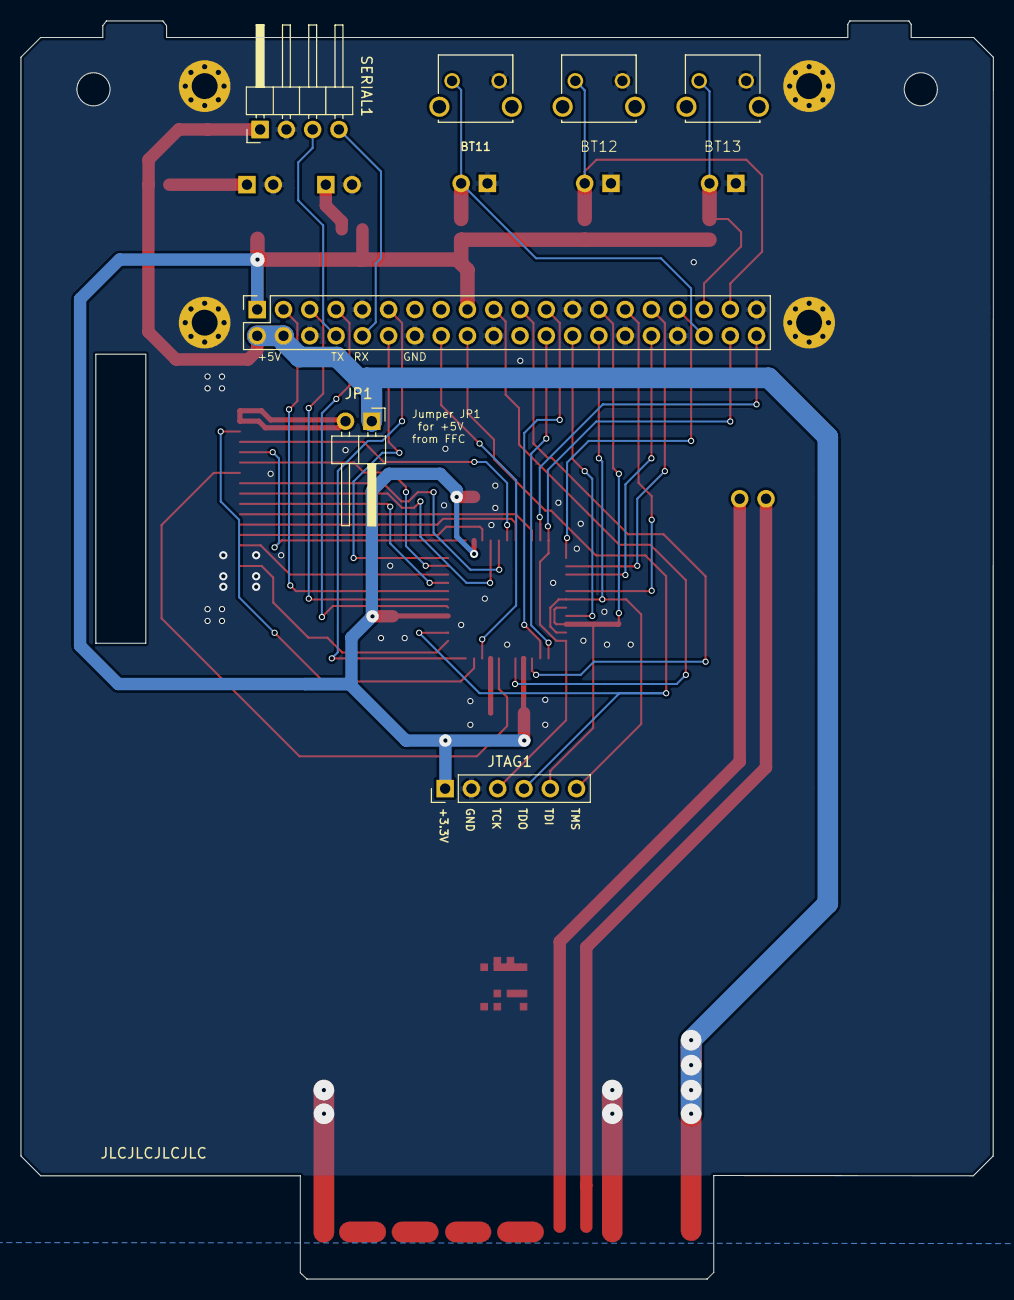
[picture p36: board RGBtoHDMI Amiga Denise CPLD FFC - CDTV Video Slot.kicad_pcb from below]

Board: 2 copper layers, 94.0 x 121.6 mm, 34 parts (7 on the bottom side), 51 nets.

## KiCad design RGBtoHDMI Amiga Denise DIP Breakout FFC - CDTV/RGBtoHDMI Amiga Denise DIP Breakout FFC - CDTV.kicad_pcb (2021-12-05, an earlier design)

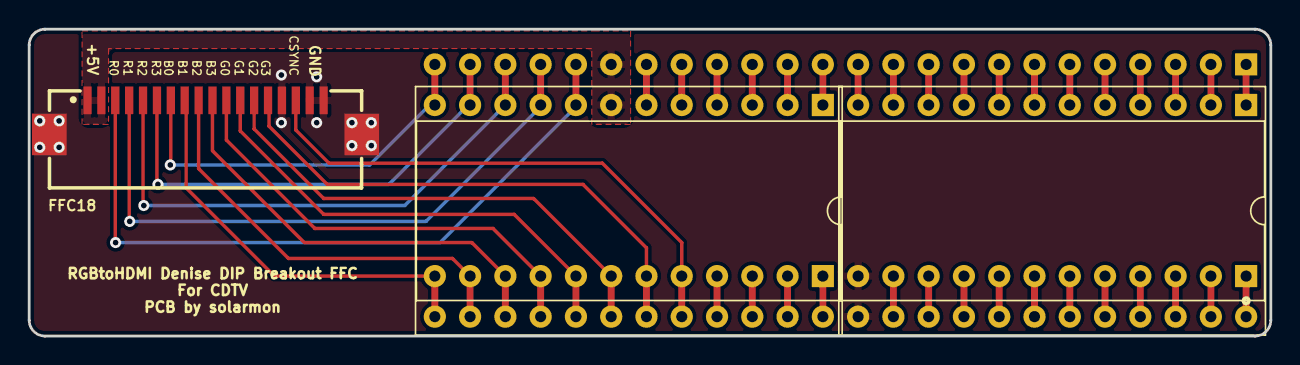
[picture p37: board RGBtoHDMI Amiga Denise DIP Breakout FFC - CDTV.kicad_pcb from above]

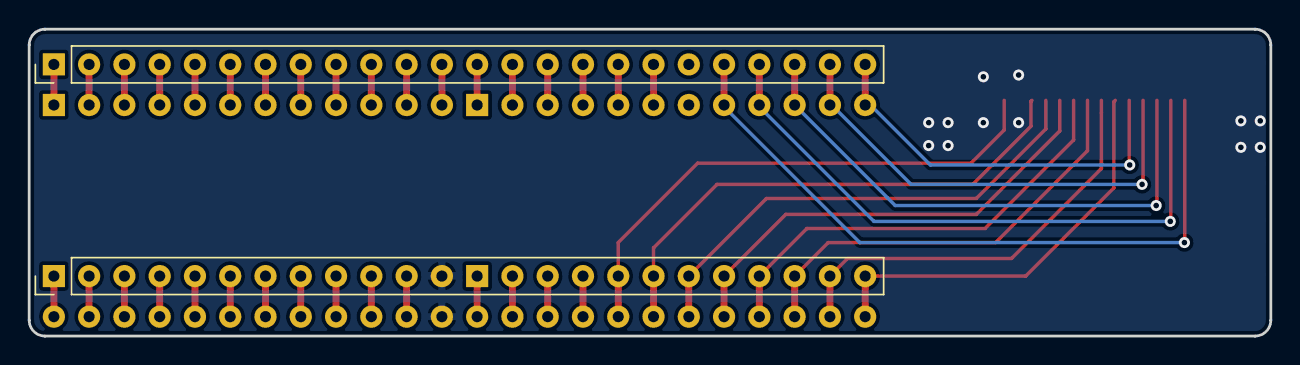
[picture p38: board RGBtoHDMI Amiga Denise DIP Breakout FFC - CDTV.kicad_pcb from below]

Board: 2 copper layers, 89.4 x 22.1 mm, 5 parts (2 on the bottom side), 48 nets.

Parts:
FFC18: Conn_01x18; FPC-SMD_X10B25U18T
JDenise1, JDenise2: Conn_02x12_Counter_Clockwise; DIP-24_W15.24mm_Socket
JMainBoard1, JMainBoard2: Conn_01x24; PinHeader_1x24_P2.54mm_Vertical_smaller

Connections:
+5V: FFC18.1, FFC18.2, JDenise2.7, JMainBoard1.19
/7M: JDenise2.23, JMainBoard2.14
/B0: FFC18.7, JDenise2.12, JMainBoard1.24
/B1: FFC18.8, JDenise2.13, JMainBoard2.24
/B2: FFC18.9, JDenise2.14, JMainBoard2.23
/B3: FFC18.10, JDenise2.15, JMainBoard2.22
/CDAC: JDenise2.22, JMainBoard2.15
/CSYNC: FFC18.16, JDenise2.20, JMainBoard2.17
/G0: FFC18.11, JDenise2.16, JMainBoard2.21
/G1: FFC18.12, JDenise2.17, JMainBoard2.20
/G2: FFC18.13, JDenise2.18, JMainBoard2.19
/G3: FFC18.14, JDenise2.19, JMainBoard2.18
/R0: FFC18.3, JDenise2.8, JMainBoard1.20
/R1: FFC18.4, JDenise2.9, JMainBoard1.21
/R2: FFC18.5, JDenise2.10, JMainBoard1.22
/R3: FFC18.6, JDenise2.11, JMainBoard1.23
GND: FFC18.15, FFC18.17, FFC18.18, FFC18.MP, JDenise1.13, JMainBoard2.12
unnamed: JDenise1.1, JMainBoard1.1
unnamed: JDenise1.2, JMainBoard1.2
unnamed: JDenise1.3, JMainBoard1.3
unnamed: JDenise1.4, JMainBoard1.4
unnamed: JDenise1.5, JMainBoard1.5
unnamed: JDenise1.6, JMainBoard1.6
unnamed: JDenise1.7, JMainBoard1.7
unnamed: JDenise1.8, JMainBoard1.8
unnamed: JDenise1.9, JMainBoard1.9
unnamed: JDenise1.10, JMainBoard1.10
unnamed: JDenise1.11, JMainBoard1.11
unnamed: JDenise1.12, JMainBoard1.12
unnamed: JDenise1.14, JMainBoard2.11
unnamed: JDenise1.15, JMainBoard2.10
unnamed: JDenise1.16, JMainBoard2.9
unnamed: JDenise1.17, JMainBoard2.8
unnamed: JDenise1.18, JMainBoard2.7
unnamed: JDenise1.19, JMainBoard2.6
unnamed: JDenise1.20, JMainBoard2.5
unnamed: JDenise1.21, JMainBoard2.4
unnamed: JDenise1.22, JMainBoard2.3
unnamed: JDenise1.23, JMainBoard2.2
unnamed: JDenise1.24, JMainBoard2.1
unnamed: JDenise2.1, JMainBoard1.13
unnamed: JDenise2.2, JMainBoard1.14
unnamed: JDenise2.3, JMainBoard1.15
unnamed: JDenise2.4, JMainBoard1.16
unnamed: JDenise2.5, JMainBoard1.17
unnamed: JDenise2.6, JMainBoard1.18
unnamed: JDenise2.21, JMainBoard2.16
unnamed: JDenise2.24, JMainBoard2.13

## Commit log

2021-11-16 Added KiCAD files
    [CDTV Front plate.FCStd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]
2021-11-16 Added KiCAD files for CDTV Denise breakout
    [RGBtoHDMI Amiga Denise DIP Breakout FFC - CDTV-B_Cu.gbr, RGBtoHDMI Amiga Denise DIP Breakout FFC - CDTV-B_Mask.gbr, RGBtoHDMI Amiga Denise DIP Breakout FFC - C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]
2021-12-06 Added L+R audio points
    [RGBtoHDMI Amiga Denise CPLD FFC - CDTV Video Slot.kicad_pcb, RGBtoHDMI Amiga Denise CPLD FFC - CDTV Video Slot.sch]
2021-12-10 Added RGBtoHDMI Amiga Denise DIP Breakout FFC - CDTV v2
    [RGBtoHDMI Amiga Denise CPLD FFC - CDTV Video Slot - Face Plate-B_Cu.gbr, RGBtoHDMI Amiga Denise CPLD FFC - CDTV Video Slot - Face Plate-B_Mask.gbr, RGBtoHDMI A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]
2021-12-10 Added more pictures
    [RGBtoHDMI Amiga Denise DIP Breakout FFC - CDTV v2.kicad_pcb]
2021-12-11 Added LED install guide pictures
